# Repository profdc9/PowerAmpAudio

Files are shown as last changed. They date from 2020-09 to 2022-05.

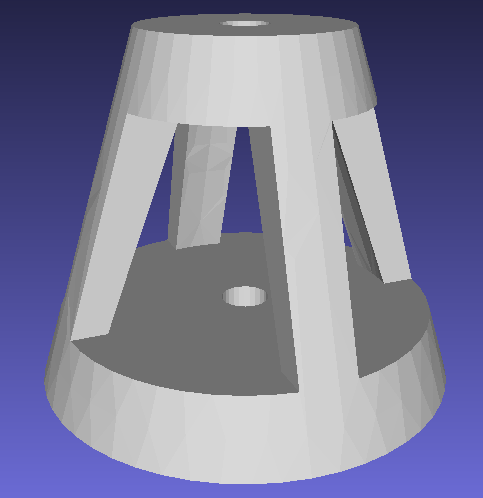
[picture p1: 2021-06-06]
CAD/example-3.5mm.png

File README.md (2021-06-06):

# Modified C300 Amplifier

This is a PCB layout by Daniel Marks based on Michael Chua's C300 amplifier which can be found at:

https://www.ampslab.com/c300.htm

This is a project designed to be a good quality amplifier that is achieves good quality distortion (< 0.1% THD at 10 kHz and 300 W per channel max), and is both educational (to study for electronics engineering and hobbyist use) and archival (to be useful long into the future, or "future proofed").  This is a layout from 2020 but it is assumed that decades into the future, relatively few bipolar transistor models will be available as through-hole and discrete component electronics become ever more rare.  Through-hole and discrete devices are currently being phased out from major manufacturers, however, Chinese and other second-source manufacturers are still producing them.  Therefore emphasis with this design has been placed on keeping the design simple with a minimal number of part types and flexible substitution, perhaps at the expense of the performance that could be achieved at using the very best parts available in 2020.  

There are five PCBs in this project:

1.  PowerampC300 - a C300 power amplifier that uses TO220 transistors (BCE layout) as the intermediate power transistors, with the benchmark devices being MJE15032/MJE15033.
2.  PowerampC300TO126 - the same power amplifier that uses TO126 devices (ECB layout), the benchmark devices being MJE340/350.
3.  A power conditioning board (PowerCond) intended to provide clean power to the PCBs and isolate the power between the channels, as well as enable the use of switching power supplies by filtering switching noise.  It may also be used with a conventional unregulated supply (diode bridge and filter capacitors).
4.  A PCB with XLR to unbalanced conversion.  This is currently using a THAT1200 part but can be reconfigured for other types of chips from Analog Devices SSM2131 or Texas Instruments INA134.  
5.  SoftStart - a relay based soft start which supports external triggering mode from an AV receiver.  This PCB prevents current inrush when an unregulated supply with large reservoir capacitors are used.

The small signal transistors are of 2N5401/2N5551 type (though MPSA42/MPSA92 may be substituted, with the THD approximately doubling because of the reduced loop bandwidth as the beta of these transistors is smaller).  Q1/Q2 may be advantageously substituted with MPSA18 if available to decrease the noise at the input.

The power transistors may be of many TO-247 or TO-264 types as available.  The footprints for the power transistors allow for under PCB, over PCB, or surface lead mounting.

There are only three types of transistors that are needed for this project to keep : a small signal, high voltage type (for example 2N5401/2N5551), a medium power type (for example MJE15032/MJE15033 or MJE340/MJE350), and a high power output stage type (for example MJL3281A/MJL1302A).

The original design calls for mica capacitors for C9 and C6.  C6 generally is not needed and can be left open, but 10 pF maximum should be used for a small amount of phase lead if required.  A good choice for C9 is 100 pF which should provide reasonable stability for a wide variety of transistor types.  As silver mica capacitors are becoming more rare, C0G/NP0 capacitors with 1 kV minimum voltage may be substituted in a pinch.  Most of the other capacitors of 0.1 uF size are either polypropylene film capacitors (7.5 to 10 mm footprint) or ceramic disc type (5 mm footprint).  As polystyrene capacitors are already exceedingly rare in 2020, the best substitute is likely to be polypropylene capacitors.  In particular, X7R/Y5V types use a ferroelectric dielectric and therefore are "microphonic" in that the sound will be converted to a small voltage by these capacitors, in a manner similar to that of an electret microphone, and therefore these should be avoided except in a handful of places where their influence is minimized.

C1 is a 10 uF decoupling polyethylene film capacitor.  It is fairly large.  Should it not be available, something like two 22 uF, 100 to 250V (larger the better) electrolytics can be used, wired in series with negative terminals joined.  Electrolytics, however, have somewhat higher distortion than film capacitors.

Resistors should be of metal-film types, except R33-R40 which may be wirewound.

THe inductor L1 is an output inductor intended to improve stability for highly capacitive loads (e.g. electrostatic speakers).  It may be a coil of 16-18 gauge magnet wire, 10 turns and 25 mm diameter.

All of the gerbers are available as well as the Kicad files, which is an open-source PCB layout program.  The PCBs are two-layer boards.  Modelling of the amplifier (both open-loop and distortion) has been performed with Qucs-S/ngspice with these simulation files included.

# WARNINGS

This project involves high voltages, high currents, and high power.  You must take proper precaution to prevent injury or death from electrocution.  The voltages and currents could cause excessive heating or electrical fires.  You must take proper precautions to properly ground equipment, especially mains voltages, so that these do not come in contact with the chassis possibly cause electrocution.  The chassis of the equipment should be attached to earth ground with proper fusing.  Large amounts of energy may be stored in capacitors.  If this energy is suddently discharged, for example from accidentally shorting the terminals, injury may result, and the capacitor may be damaged or explode.  Wiring electrolytic capacitors in reverse polarity is likely to cause damage or explosion.  This list of potential dangers is not exhaustive; you assume all risk.

# Part substitutions

## Transistors

The small signal transistors are chosen to be 2N5551 (NPN) and 2N5401 (PNP).  These should have Vcemax of at least 150 V, minimum collector current 100 mA, hFE at least 100, and gain-bandwidth product 100 MHz or greater.  MPSA42 (NPN) and MPSA92 (PNP) may be subsituted for 2N5551/2N5401, however, these have reduced gain so that the loop gain is reduced and the distortion is somewhat increased.

Because the lead order of TO-126 transistors (ECB) is the opposite of the lead order for TO-220 transistors, TO-126 made be substituted for TO-220 (and vice versa) as long as the device is placed reversed in the PCB (pin 1 and pin 3, and pin 3 at pin 1).  This can not be done with the driver transistors Q15/Q16 because these are against the heat sink and therefore can not be reversed in place.  Therefore, if one wishes to use TO-220 driver transistors but TO-126 VAS transistors, one should use the PowerampC300 project (and not the PowerampC300TO126 project) so that the driver transistors will be oriented correctly to be placed against the heatsink.

The VAS transistors (Q10 and Q12) should have Vcemax at least 200 V, minimum collector current 100 mA, hFE at least 70 (more the better), and gain-bandwidth product at least 15 MHz.  Suitable devices are:

TO-220:  MJE15032 (NPN), MJE15033 (PNP), 3DA4793 (NPN), 3CA1387 (PNP)

TO-126:  MJE340 (NPN), MJE350 (PNP), 2SC3503 (NPN), 2SA1381 (PNP)

The bias servo transistor doesn't need to be anything special should have Vcemax at least 200 V.  Suitable devices are the same types used for the VAS transistors.  

The driver transistors should have Vcemax at least 200 V, minimum collector current 1 A, hFE at least 50, and gain-bandwidth product at least 15 MHz.  Suitable devices are:

TO-220:  MJE15032 (NPN), MJE15033 (PNP), 3DA4793 (NPN), 3CA1387 (PNP)

TO-126:  MJE340 (NPN), MJE350 (PNP)

The output transistors are TO-247/TO-264/TO-3P type.  They should have Vcemax at least 200 V, minimum collector current 15 A, hFE at least 50, and power dissipation at 25 C at least 150 W.  Suitable types include:

MJL3281A (NPN) / MJL1302A (PNP)  TO-264

MJL3281W (NPN) / MJL1302W (PNP)  TO-247

NJW0281 (NPN) / NJW0302 (PNP) TO-3P

2SC5200 (NPN) / 2SA1943 (PNP) TO-264

MJL21194 (NPN) / MJL21193 (PNP) TO-264

MJW21194 (NPN) / MJW21193 (PNP) TO-247

There are known to be versions of the MJL15032, MJL15032, NJW0281, NJW0302 available from by Chinese vendors (search lcsc.com).  These may have sufficient performance for creating lower cost implementations of the amplifier. 

## Power terminals

The power terminals are designed to take the common 5.0/5.08 mm spaced screw terminal blocks.  Alternatively, 6.35 mm male spade terminals with 5.0 mm pitch pins may be soldered into the board.  Screw terminal blocks are easier to swap out but are not as secure, while spade terminals can be quite secure but sometimes difficult to remove if required.

## Audio connectors

To connect unbalanced audio to the amplifier PCBs and to the balanced to unbalanced PCBs, either two wires or a SMA cable may be used.  A SMA cable has the advantage of inherent shielding.  If a SMA cable is wired to an input unbalanced RCA jack, the jack should be an isolated jack with the ring of the jack wired to the input star ground where the chassis earth ground is.

## Balanced to unbalanced differential line receiver

The balanced to unbalanced PCB can be set up to preferentially use the THAT1200, but also can be configured for the THAT1240, INA134, or SSM2141.

# Building the amplifier (PowerampC300 and PowerampC300TO126)

The PCB is two-sided without any links with all components soldered to the top side.  Populate the small components first (transistors, resistors, small capacitors).  Leave the larger components such as C1, Q10, Q11, Q12, Q15, Q16, the driver transistors Q17-Q24 for later as they will make the PCB more unwieldy to work with.

Q10 and Q12 should be mounted to small vertical heatsinks sufficient of dissipating 10 W.  An insulating silicone pad or mica sheet should be placed between the collector tab and the heatsink so that the heatsink is not electrically connected to the transistor.  A bushing should be used on TO-220 types of insulate the mounting screw from the heatsink.

Q15, Q16, and Q17-Q24 are all mounted in a row to a heatsink.  There is a file "Drillpattern.pdf" which shows the position of the holes on the heatsink for the transistors which can be taped over the heatsink to mark the positions to tap.  All of these transistors should have silicone pads or mica sheets insulating the collector tabs from the heatsink.  AFTER INSTALLATION, THE HEATSINK SHOULD BE CAREFULLY CHECKED WITH A MULTIMETER TO MAKE SURE THERE IS NO CONTINUITY BETWEEN THE COLLECTORS (middle pin) OF ANY OF THE TRANSISTORS AND THE HEATSINK.  For an aluminum heatsink, M3 (metric) or 4-40 (SAE) holes may be tapped in the heatsink to mount the transistors.  After tapping, there is likely to be burrs from the tapping process, so sanding the heatsink with the a fine sandpaper is often require to remove these burrs.  These burrs may poke through a silicone pad or mica sheet and contact the transistor causing a potentially catastrophic short circuit.  If Q15 and Q16 are TO-220 transistors, a bushing should also be used to insulate the tab from the mounting screw.  It is helpful when installing the transistors to gently curl the legs away from the heatsink slightly so that they can be easily bent if a little persuasion is needed to make the position of the transistor mounting hole reach the tapped hole.  

A hole should be tapped on the heatsink above Q15 and Q16 to place the bias servo transistor Q11.  The three legs of Q11 are soldered to extension wires, and heat shrink tubing is applied to the extension wires to prevent inadvertent contact the between the wires or to the heatsink.  The other end of the wires are soldered into the PCB at the Q11 position so that Q11 is tethered to the PCB but may freely moved.  Q11 can be mounted to the heatsink similarly to how Q15 and Q16 are, using an insulating silicone or mica pad and a bushing if required.  Again, check to make sure there is no continuity between the heatsink and the collector of Q11.

The heatsink may be mounted with the transistors laying flat parallel to the PCB, or the heatsink stood upright so the transistors are sticking up from the PCB.  Which one is used depends on the case mounting and heatsink type.

After assembly carefully inspect the PCB front and back, especially solder pads for any accidental bridges or incomplete or cold solder joints.  A lighted magnifier is very helpful for this.  If joints are not being properly made, it could be because the solder is old and has bad flux or the board was not clean before starting.  This is particularly troublesome to make reliable solder joints, and fresh flux should be applied to ensure joints are properly wetted.

CONNECT THE POSITIVE SUPPLY LEADS (GND/V+) to the PCB before the negative supply leads (V-/GND).  If there is only a negative supply attached to the amplifier PCB, the amplifier may be damaged (transistors Q8 or Q9).  Before powering, the DC offset control trimmer R10 should be set to the middle position in resistance (approximately 50 ohms between wiper and contacts), and bias control trimmer R22 should be to maximum resistance (200 ohms).  

The file "Grounding.pdf" shows a diagram of how to connect the amplifier to minimize ground loops.  Pay attention to isolate the jacks from the chassis, twist the conductors of the power together, twist the conductors of the output cables together, and bond the input jacks together and possibly to one point on the chassis.

Powering up for the first time is always a nerve-racking experience.  All power connections from the transformer to the power conditioning PCB to the amplifier PCB should be thoroughly checked to ensure that both supplies are properly connected.  The best approach is to use an isolated variac with a AC current meter to power the amplifier so that the voltage may be slowly increased and it can be seen if any excessive currents are encountered.  However, if a variac is not available, one may be able to place 220 ohm, 5 watt resistors in series with the positive and negative rails so that when one initially powers on, the full current available from the power supply does not cause excessive damage to the PCB if there is a problem.  

The amplifier should first be powered up without a load.  If there is a faulty component or faulty connections, such as unreliable power connections, the amplifier may oscillate.  This sometimes often results in the destruction of Q8, and occasionally R19 and R24.  Damage to the resistors is usually obvious and can easily be tested in circuit.  Q8 can still measure properly with a diode checker in circuit but be faulty.  Therefore one should replace Q8 if there is any doubt if it is functioning correctly.

Once the amplifier has operated at full voltage without a load, a dummy load should be attached to the amplifier output.  A dummy load can be constructed, for example, from many smaller 8-ohm, 5 W sandblock or metal-oxide resistors.  For example, thirty six of these resistors, with 6 strings of resistors in parallel, each string being 6 resistors in series, makes a convenient 180 watt, 8 ohm audio load.  

The quiescent current of the class AB stage should be set.  Trimmer R22 controls the voltage bias between the bases of the NPN and PNP transistors and therefore the quiescent current.  By decreasing the resistance of R22, the quiescent current is increased.  The quiescent current of an output transistor may be measured using the voltage between the emitter of the transistor and the output of the amplifier.  With R22 at maximum resistance, this should be very close to 0 mV.  Slowly decrease the resistance of R22, measuring the increase of the voltage.  Because the voltage is across the output 0.39 ohm resistor, to achieve 35 mA quiescent current, 14 mV should be measured.  Because of differences between transistors, the quiescent currents in different transistors are likely to be slightly different.  Try to ensure that no output transistor has excessive current, perhaps exceeding 60 mA.  

Without any input to the amplifier, when the amplifier is powered up, the DC voltage measured across the 8 ohm audio load should read very close to zero, within 100 mV at most.  Trimmer R10 should be adjusted to reduce the DC offset at the output to below 10 mV.  

With the quiescent current and output DC offset adjusted, you can apply a signal to the amp.  Use an oscilloscope to measure the voltage on the audio load.  Inject a sine wave input signal into the amplifier of about 1000 Hz and 0.1 V peak.  Because the gain of the amplifier is approximately 31, this should result in a 3.1 V output on the audio load.  The signal can be generated either by a signal generator, or by a computer sound card which is input into a preamplifier.  Turn the preamplifier down and adjust the input signal amplitude.  A very clean sine wave output should be observed.

Slowly increase the amplitude of the sine wave, up to perhaps 1.0 V, so that the peak output voltage is 31 V.  A clean sine wave should still be observed.  The audio load will start to get hot, so keep the audio load on a surface (for example a ceramic dish) to insulate it from the table.  

Next, change the output from a sine wave to a square wave at 20 kHz.  A nice, clean square wave should be observed with little or no ringing.  The rise/fall time on the square wave should be about 2 microseconds or so.

Once you are confident that the amplifier is stable, you can try your (not best) speaker with it.  A pure tone should be heard without distortion.  If you are hearing hum, you may have a problem with grounding inside the amplifier or a ground loop.  If you short the input to the amplifier, and still hear hum, the problem is inside the amplifier.  Check to see that the amplifier is grounded at the input jacks (and only there) to the earth ground connection on the chassis.  If not in the amplifier, you may need to investigate if the device generating the signal has multiple ground connections inside it.

After all of this, you should be good to go.  Be careful as the amplifier has a lot of power and can damage speakers not rated for the full power.

# Building the power conditioning board

The power conditioning board is not strictly required.  However, it serves three functions.  It rectifies AC to DC when an unregulated transformer supply is used.  It serves to filter out RF noise and brief voltage spikes from the diode commutation from the amplifier, as well as any other noise coming from the mains.  The filtering is also useful is one uses switching power supplies rather than an unregulated transformer supply to filter the switching noise.  Finally, it serves as a terminal block to connect the reservoir capacitors and amplifier.  Typically, one power conditioning board is used per channel.

The common mode chokes can be constructed by hand.  Four are required for each power conditioning board.   Typically, small ferrite toroids are obtained, usually between 16 to 25 mm in outer diameter.   Small green cores available widely on sites like ebay, Amazon, or aliexpress are suitable.  The primary and secondary turns are two different colors of 18 AWG (1 mm diameter) solid copper wire.  The two wires are wound together side-by-side through the core five or six times.  When soldering the core into the PCB, the silkscreening shows how the wires are connected.  The same color wire is soldered to both pads connected by the line in the silkscreen.  The same ends of the two wires are soldered to the two pads next to each other on the same side of the PCB.  Solder should be applied to both the top side and bottom side of the pad to ensure the wire is held solidly.

The mounting holes at the corners of the PCB are intended to be grounded to the case through standoffs to shunt the filtered RF noise signal to the case.  

# Building the SoftStart board

The SoftStart board is relatively straightforward to build.  Special attention should be paid to acquiring X2 capacitors for C1 and C2.  The extra non-plated through holes in the PCB are so that the mains and switch wires soldered to the PCB can be threaded through the PCB and collared with a cable tie as a strain relief so that it does not pull out of the PCB.  The cable tie will prevent stress from being applied to the solder joint on the PCB.  Generally, a cover should be placed over the back side of the PCB (for example a polycarbonate sheet) to prevent contact of the solder joints with the case.  It is highly recommend to put heat shrink tubing over any exposed mains connections, for example, at the power entry panel, switch or fuse holder.  

Depending on the size of the reservoir capacitors in your amplifier, it may be necessary to change the 150 ohm resistors to a smaller value and allow a somewhat larger charging current before the resistors are bypassed by the relay.  This depends on the peak current that is permitted.

# Building the XLR to Unbalanced board

This board uses the THAT1200 balanced line receiver to transform the signal from a balanced XLR connector to an unbalanced signal.  The unbalanced signal may be connected from the XLR to Unbalanced board to the amplifier board with a shielded SMA cable to prevent noise pickup.  If the THAT1200 is not available, the THAT1240, INA134, or SSM2141 balanced line receivers may be used.  In this case, C5 and C17 should be omitted and JP1 and JP2 are shorted.

The transistors Q1 and Q2 should have heatsinks attached and fitted with pads and bushings to electrically isolate the heatsink from the collector.  J12 is a ground terminal block from which a grounding wire and lug may be extended to the common input grounding point on the chassis of the amplifier.

# Different types of feedback

There are three kinds of feedback that can be customized to provide a tradeoff of distortion vs. loop stability.  Some audiophiles like to attain the minimum distortion.  It is likely that the distortion is sufficiently low, especially at power levels significantly below the maximum power, that distortion is not likely to be noticed.  It is highly recommended when using compensation methods that could be more unstable that the inductor L1 is installed, as any significant capacitive loading is likely to cause oscillation.

For the audiophile true believers, three feedback options are provided: Conventional Miller Compensation (CMC), Two-Pole Compensation (TPC), and Output Inclusive Two-Pole Compensation (OITPC).  Small value capacitors are ideally silver mica type (470 pF or less), but NP0/C0G types can work as well.  The 100 nF are polypropylene film capacitors, 100 V or more.

## Conventional Miller Compensation (CMC)
As shown, the circuit is configured for CMC.  In this case, C9=150 pF, C3=150 pF, C25 is a shorting wire, R18, C20, and C24 are not included.  For slightly less distortion, C9=100 pF and C3=100 pF. 

## Two-Pole Compensation (TPC)
To configure for Two-Pole Compensation, C3 and C20 are not included, C9 and C25 are 220 pF, R18 is 2k2, and C24 is 100 nF.  Simulations suggest that at mid range frequencies, distortion can be decreased by 14 dB, and at 10 kHz by 8 dB.

## Output Inclusive Two-Pole Compensation (OITPC)
OITPC is a relatively new option that is included for study and experimentation.  To configure for OITPC, C9 and C25 are 100 pF, R18 is 390 ohms, C20 is 100 pF, and C24 is 100 nF, C3 is not included.  

# A brief explanation of the operation of the amplifier
The amplifier is a class AB configuration with approximately 34 dB of gain and employing global negative feedback, as well as local feedback in the form of compensation.

Capacitor C1 is a film capacitor that isolates DC from the input but passes frequencies above 2-3 Hz.  Q1 and Q2 are a differential pair for which the error feedback signal is the current through the collector of Q1.  

R6, R7, R8, R9, and R10 are used to null any DC offset on the output, with the potentiometer R10 fine-tuning the DC offset.  Q7 is a constant current source with a fixed voltage between its base and emitter which is determined by the red LED.  The emitter resistor R12 sets the current at approximately (LED voltage=2.0 V - 0.7 VBE) / R12.  The same LED also sets the voltage on the emitter of Q12 which is likewise a constant current source for the VAS (voltage amplification stage).

Q5 and Q6 have their bases joined together and fixed at a voltage 33 V above ground so that their emitters are fixed at one diode drop below the bases.  This is a cascode configuration that holds the collectors of Q1/Q2 at a constant voltage as to reduce the Miller effect.  This is also helpful to limit the VCE of Q1 and Q2 in case a low voltage transistor such as MPSA18 is used, which has a maximum VCE of 45 V.

Q3 and Q4 are a current mirror forming a high impedance load for the differential pair so that high gain is achieved.  The output impedance of Q3 is limited by the Early effect which can be at quite a high voltage for a high voltage transistor such as 2N5401.  R5 and C3 form a high-pass network which serves to help increase the phase margin at high frequencies by reducing the open loop gain at high frequencies.

Because Q3 acts as a high impedance load, the current from Q1 is steered into the base of Q8 which is an emitter-follower configuration.  This minimizes the load of Q1.  Q8 is a vulnerable transistor as it drives Q10 with whatever current is necessary to maintain feedback, even when the amplifier is at the rails.  To prevent the current in the collector of Q8 from exceeding safe operating limits, transistor Q9 steals base current from Q8 when the current in the VAS exceeds about 20 mA.  This is one diode drop across the emitter-base of Q9 divided by resistor R19.  If Q9 is not present a brief excursion into the rails can destroy Q8 as the voltage and current on it can greatly exceed tolerable limits.

Q10 and Q12 are a conventional one-sided VAS arrangement, with Q12 being a constant current source of about 11 mA, and Q10 being a common-emitter configuration.  This produces a second high gain stage, which when combined with the gain of the differential pair, produces the needed open loop gain in the amplifier.

With C9 at 100-150 pF and C25 short circuited, this amplifier employs conventional Miller compensation.  This is a negative feedback arrangement that introduces a pole into the open loop gain of the amplifier.  It is the main mechanism stabilizing the amplifier.  The pole ensures that any other poles in the amplifier due to limited component bandwidth occur with a gain margin of 10 dB or greater.  By including a capacitor at C20, the compensation includes the output signal and partially compensates for the relatively slow speed of the output transistors.

Transistor Q11 is in a "rubber diode" configuration that is an adjustable fixed bias to achieve a quiescent current in the output transistors Q17 to Q24.  The voltage differences between the bases Q17, Q19, Q21, and Q23 and Q18, Q20, Q22, and Q24 determine the quiescent current.  More quiescent current generally reduces crossover distortion but dissipates more constant power.  Potentiometer R22 is used to adjust the quiescent current, which is typically about 10 to 15 mA per output transistor, and is typically measured across the resistors R33-R40. 

D13 and D14 are catch diodes that limit the output current at very high current output.  When the diodes are forward biased, VAS current is diverted directly to the output, limiting the base current of Q13 and Q14 and therefore output current of the amplifier.

Q13 and Q14 are a V-I limiter which limits the output current when the impedance of the load drops below 2 ohms.  The voltage is sensed on the emitter resistors R39 and R40.  This is reduced by the divider networks R26/R29 and R27/R30.  When the emitter-base voltage on Q13 or Q14 exceeds one diode drop, or about 0.6 V, the transistors start to steal base current from Q15/Q16 which limits the output current.  This acts as a temporary protection for the output transistors to keep them within the safe operating area.  However, it is recommended to use a fuse on the power supply as well so that in case of a prolonged short circuit, the fuse blows.

Q15/Q16 and the output transistors Q17-Q24 form a conventional Darlington class AB stage.  As the VAS can source a maximum of about 10 mA, the hFE of Q15/Q16 is about 50, and the hFE of Q17-Q24 is about 50, the maximum current is on the order of 15 to 25 A, which corresponds to a very high peak power.  However, four transistors are needed as the thermal load is shared between them, and dividing the current load between them ensures they are kept within the SOA.  It is recommended that if 2SC5200/2SA1943 transistors are used, the maximum supply voltage is limited to 50 to 55 V as the SOA of these transistors is somewhat less than the MJL3281A/MJL1302A which can handle up to 70 V.

R52 and U1 are yet another optional feature to protect the amplifier.  When the output current exceeds 8 A, the optotriac U1 LED turns on which triggers the triac.  This short circuits the bias at the output so that the catch diodes D13 and D14 divert the VAS current into the output and the output is mostly turned off.  The output remains off until the power is cycled.  This feature may be needed for those that torture and damage the amplifier regularly, but is probably not needed for ordinary use.

This amplifier can be used with vertical MOSFETs by substituing Q17, Q19, Q21, and Q23 with IRFP240 and Q18, Q20, Q22, and Q24 with IRFP9240.  However, R21 needs to be substituted with a much larger resistance so that the gate-to-gate voltage is much larger, on the order of 1.5k ohms.  Secondly, a diode connected transistor (base and collector shorted) needs to be placed in series with the emitter of Q11, and this diode connected transistor should be connected to the heatsink.  The necessary quiescent current for MOSFETs in order to achieve low crossover distortion is much greater than that of BJTs, on the order of 200 mA for all the transistors. The voltage between the gates will be on the order of 2 VT or about 8 V.  This however has not been extensively tested at the time of writing.

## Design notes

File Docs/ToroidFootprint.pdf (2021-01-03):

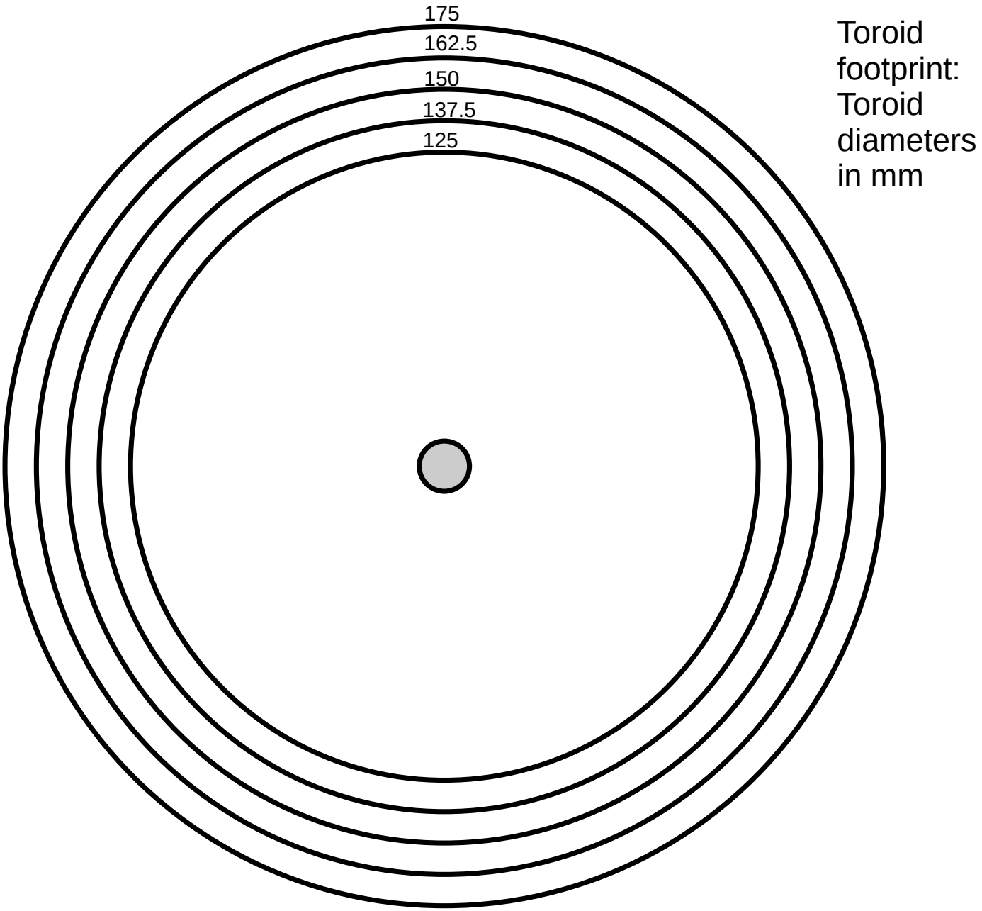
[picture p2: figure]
Toroid footprint: Toroid diameters in mm

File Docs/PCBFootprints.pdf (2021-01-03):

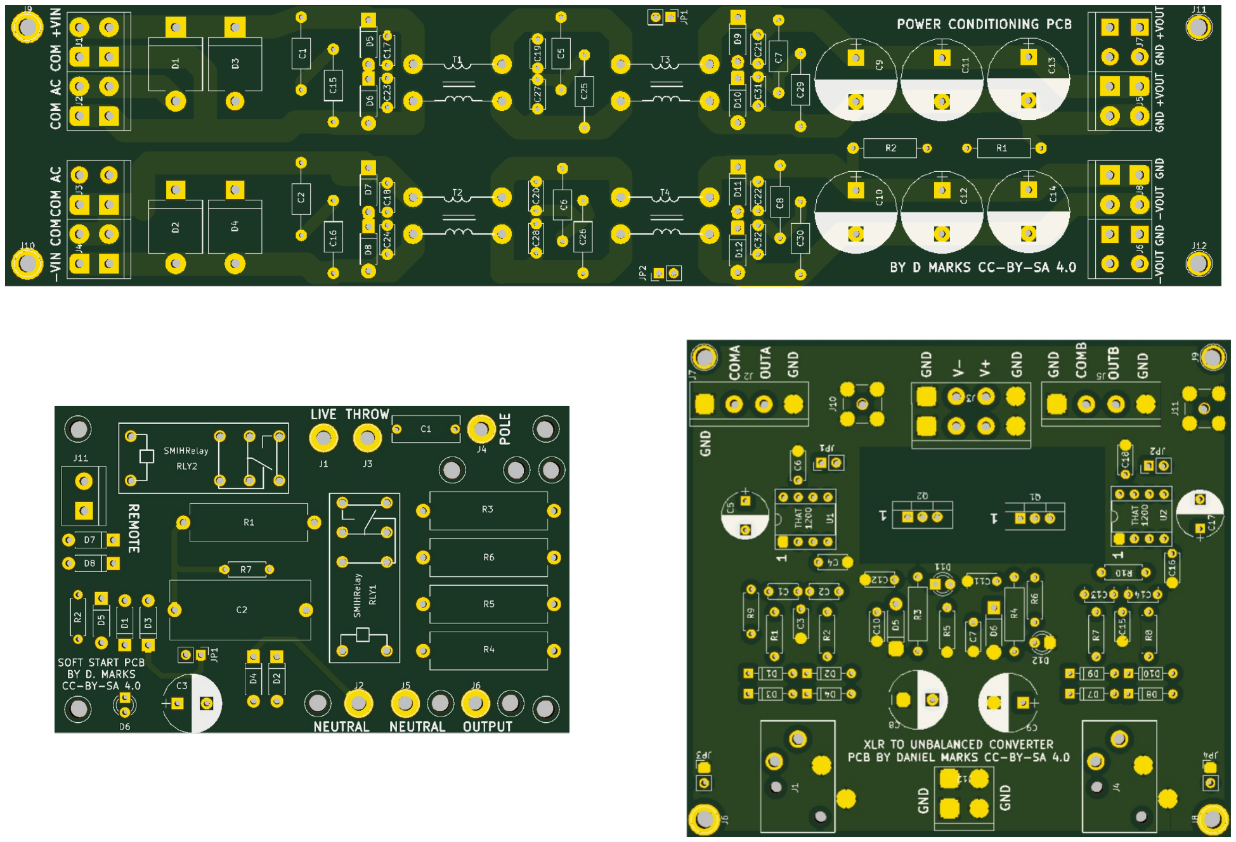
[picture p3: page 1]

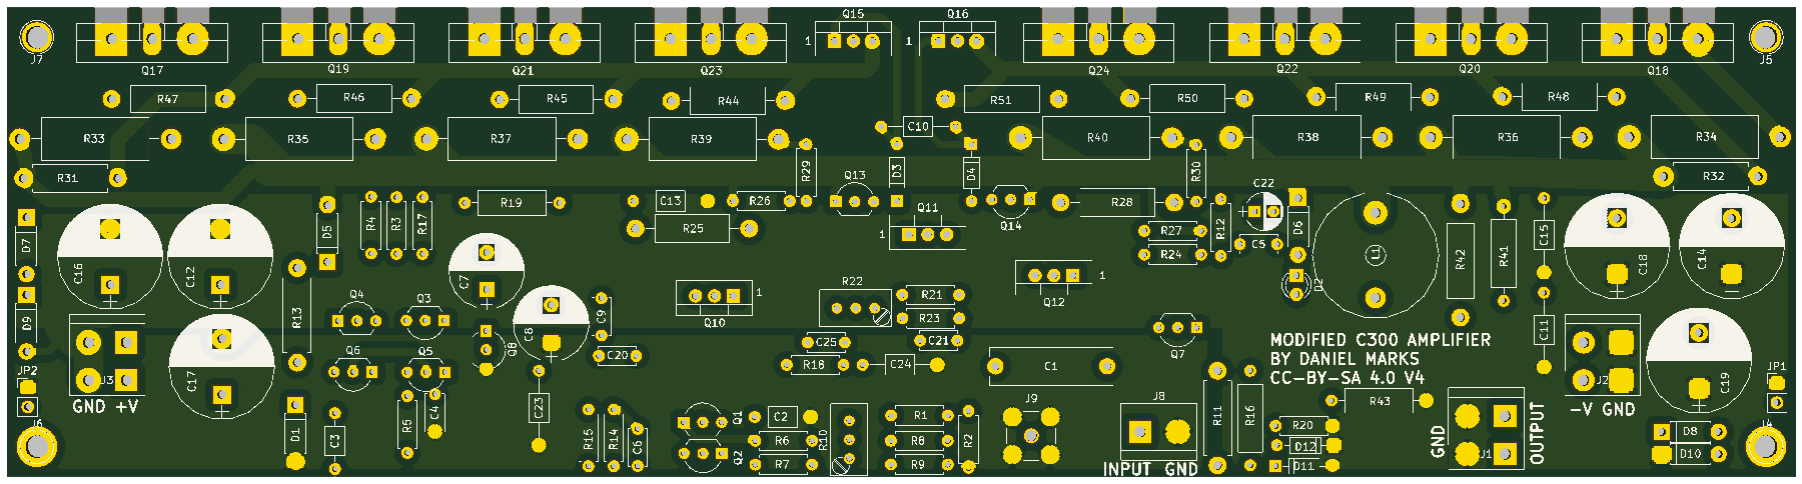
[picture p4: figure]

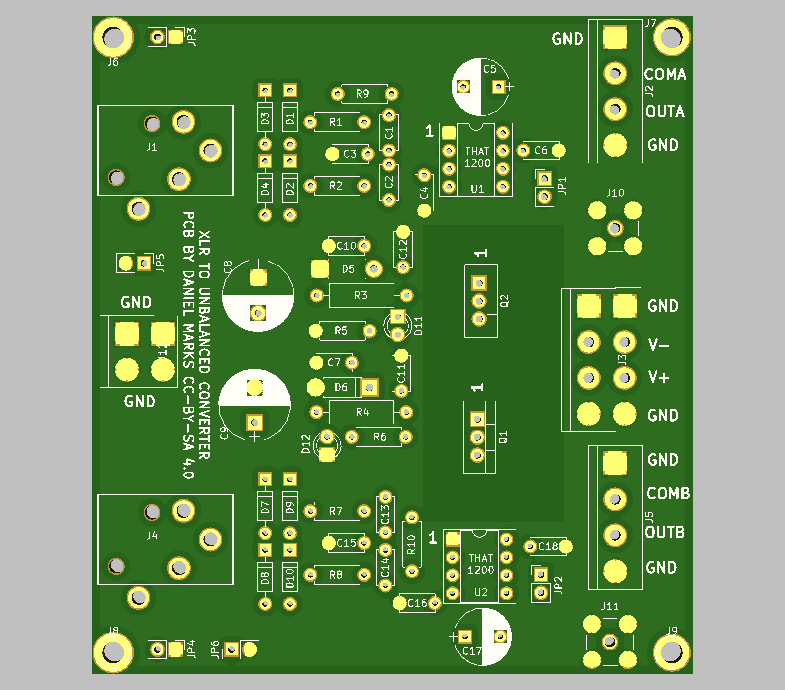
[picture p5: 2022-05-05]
XLRtoBal/XLRtoBal.png

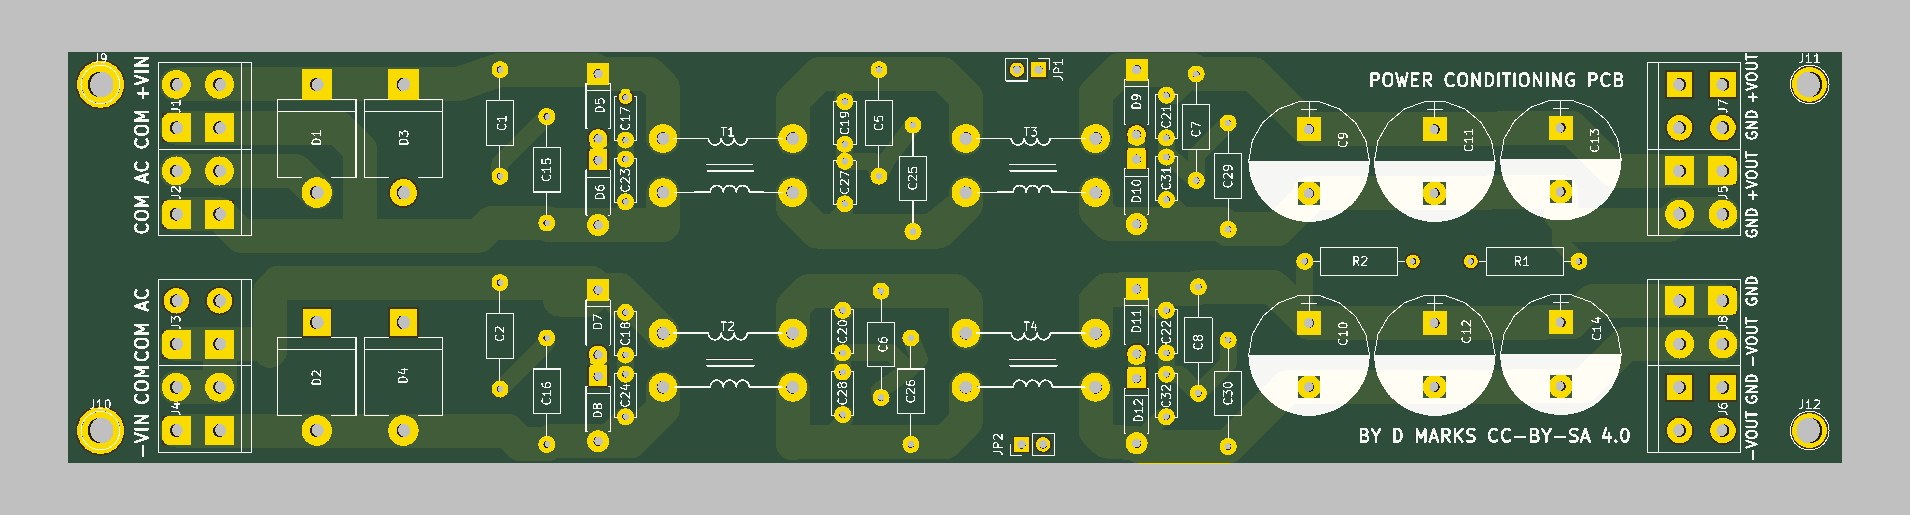
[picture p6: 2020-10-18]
PowerCond/PowerCond.png

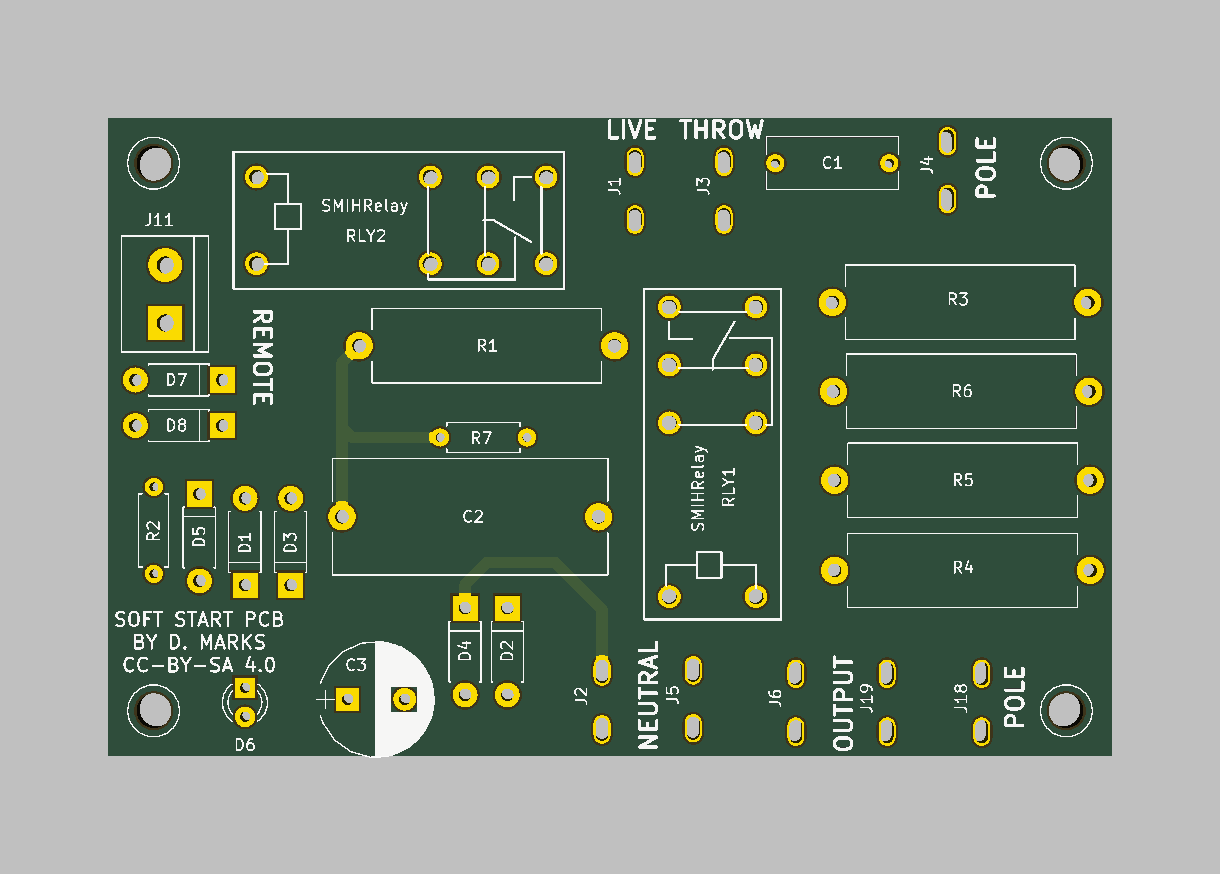
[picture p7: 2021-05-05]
SoftStart/SoftStart.png

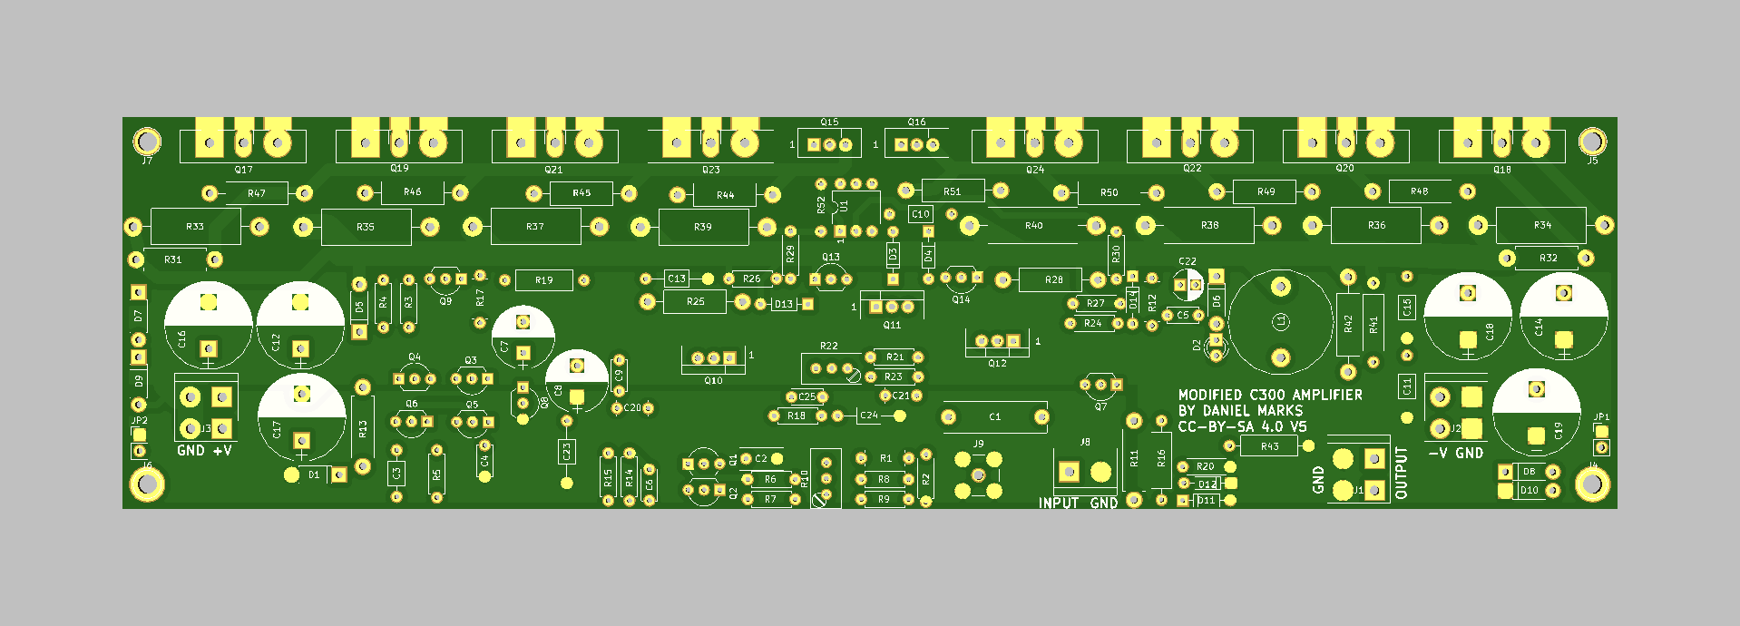
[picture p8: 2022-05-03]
PowerampC300/PowerampC300.png

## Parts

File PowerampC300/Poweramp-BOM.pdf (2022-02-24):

PowerampC300

Designator | Footprint
C1 | 10 uF polypropylene film capacitor > 63 V
C10,C11,C13,C15,C23,C24 | 0.1 uF / 100 nF polypropylene film capacitor > 250V
C12,C14,C16,C17,C18,C19 | 100 uF electrolytic capacitors > 160 V
C2 | 470 pF polypropylene film capacitor
C21 | NC (could place 10 uF ceramic here)
C22 | NC (could place 47 uF > 50V electrolytic here)
C25 | 0 ohm resistor (¼ watt) or wire
C3 | 100 or 150 pF mica or ceramic C0G capacitor
C4,C5 | 0.1 uF / 100 nF ceramic disc capacitor
C6,C20 | NC
C7,C8 | 1000 uF, 10 V electrolytic capacitor
C9 | 100 or 150 pF mica or ceramic C0G capacitor
D1 | 33 V zener diode
D2 | 3 mm RED LED
D3,D4,D11,D12,D13,D14 | 1N4148 DO-35 diode
D5,D6 | 1N4007 DO-41 diode
D7,D8,D9,D10 | 44 V zener diodes
J1,J2,J3 | Male spade quick connectors (or terminal blocks)
J4,J5,J6,J7 | NC
J8 | 2 position 5 mm terminal block
J9 | SMA connector
JP1,JP2 | 2 pin 2.54 mm spacing male pin header
L1 | air core 1 uH (approximate) inductor, 18 gauge/1 mm wire
Q11,Q12,Q15 | TO-220 MJE15032
Q10,Q16 | TO-220 MJE15033
Q17,Q19,Q21,Q23 | TO-264 MJL3281A
Q18,Q20,Q22,Q24 | TO-264 MJL1302A
Q3,Q4,Q8,Q9,Q14 | TO-92 2N5401
Q1,Q2,Q5,Q6,Q7,Q13 | TO-92 2N5551
R1,R5,R17 | ¼ watt 1000 ohms
R10 | 100 ohm potentiometer
R11 | 3 watt 6.8k ohms
R12 | ¼ watt 200 ohms
R13 | 3 watt 5.6k ohms (could use 6.8k ohms here)
R15 | ¼ watt 330 ohms
R16 | 1 watt 6.8k ohms
R18 | NC
R19 | 3 watt 33 ohms
R2,R14 | ¼ watt 10k ohms
R20 | ¼ watt 10 ohms
R21 | ¼ watt 390 ohms
R22 | 200 ohm potentiometer
R24,R29,R30 | ¼ watt 120 ohms
R25,R28 | 3 watt 6.8k ohms
R26,R27 | ¼ watt 33 ohms
R3,R4 | ¼ watt 180 ohms
R31,R32 | 3 watt 33 ohms
R33,R34,R35,R36,R37,R38,R39,R40 | 5 watt 0.39 ohms, noninductive sandblock resistor

PowerampC300

R41 | 3 watt 4.7 ohms
R42 | 3 watt 4.7 ohms
R43 | 3 watt 10k ohms
R44,R45,R46,R47,R48,R49,R50,R51 | 1 watt 1 ohm
R6,R7,R23,R52 | ¼ watt 100 ohms
R8,R9 | ¼ watt 56 ohms
U1 | NC

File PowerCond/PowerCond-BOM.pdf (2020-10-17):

PowerCond

Page 1

Source: | E:/Poweramp/PowerCond/PowerCond.sch
Date: | 10/16/2020 9:42:15 PM
Tool: | Eeschema 4.0.7
Component Count: | 62
Ref | Value
C1 | 1 uF, 250 V polypropylene
C2 | 1 uF, 250 V polypropylene
C5 | 1 uF, 250 V polypropylene
C6 | 1 uF, 250 V polypropylene
C7 | 1 uF, 250 V polypropylene
C8 | 1 uF, 250 V polypropylene
C9 | 100 uF, 160 V electrolytic
C10 | 100 uF, 160 V electrolytic
C11 | 100 uF, 160 V electrolytic
C12 | 100 uF, 160 V electrolytic
C13 | 100 uF, 160 V electrolytic
C14 | 100 uF, 160 V electrolytic
C15 | 1 uF, 250 V polypropylene
C16 | 1 uF, 250 V polypropylene
C17 | 1 nF, 1 kV ceramic disc capacitor
C18 | 1 nF, 1 kV ceramic disc capacitor
C19 | 1 nF, 1 kV ceramic disc capacitor
C20 | 1 nF, 1 kV ceramic disc capacitor
C21 | 1 nF, 1 kV ceramic disc capacitor
C22 | 1 nF, 1 kV ceramic disc capacitor
C23 | 1 nF, 1 kV ceramic disc capacitor
C24 | 1 nF, 1 kV ceramic disc capacitor
C25 | 1 uF, 250 V polypropylene
C26 | 1 uF, 250 V polypropylene
C27 | 1 nF, 1 kV ceramic disc capacitor
C28 | 1 nF, 1 kV ceramic disc capacitor
C29 | 1 uF, 250 V polypropylene
C30 | 1 uF, 250 V polypropylene
C31 | 1 nF, 1 kV ceramic disc capacitor
C32 | 1 nF, 1 kV ceramic disc capacitor
D1 | 10A10
D2 | 10A10
D3 | 10A10
D4 | 10A10
D5 | 1N4755A, 44 V zener diode
D6 | 1N4755A, 44 V zener diode
D7 | 1N4755A, 44 V zener diode
D8 | 1N4755A, 44 V zener diode
D9 | 1N4755A, 44 V zener diode
D10 | 1N4755A, 44 V zener diode
D11 | 1N4755A, 44 V zener diode
D12 | 1N4755A, 44 V zener diode
J1 | 2 position terminal block
J2 | 2 position terminal block

PowerCond

Page 2

J3 | 2 position terminal block
J4 | 2 position terminal block
J5 | 2 position terminal block
J6 | 2 position terminal block
J7 | 2 position terminal block
J8 | 2 position terminal block
JP1 | 2 position pin header 2.54 mm spacing
JP2 | 2 position pin header 2.54 mm spacing
R1 | 220k ½ watt
R2 | 220k ½ watt
T1 | Common-mode choke
T2 | Common-mode choke
T3 | Common-mode choke
T4 | Common-mode choke

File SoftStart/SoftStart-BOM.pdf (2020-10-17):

SoftStart

Page 1

Source: | E:/Poweramp/SoftStart/SoftStart.sch
Date: | 10/16/2020 9:46:26 PM
Tool: | Eeschema 4.0.7
Component Count: | 37
Ref | Value
C1 | 10 nF X2 capacitor
C2 | 1 uF X2 capacitor
C3 | 1000 uF, 50 V electrolytic capacitor
D1 | 1N4007
D2 | 1N4007
D3 | 1N4007
D4 | 1N4007
D5 | 1N4749, 24 V zener diode
D6 | LED
D7 | 1N4742, 12 V zener diode
D8 | 1N4742, 12 V zener diode
J11 | 2 pin terminal block
R1 | 220R, 5 W sandblock resistor
R2 | 2k2, ¼ watt resistor
R3 | 150R, 5 W sandblock resistor
R4 | 150R, 5 W sandblock resistor
R5 | 150R, 5 W sandblock resistor
R6 | 150R, 5 W sandblock resistor
R7 | 1M, ¼ watt resistor
RLY1 | Omron G2RL-1-DC24 or equivalent, 24 volt coil, 12 A capacity
RLY2 | Omron G2RL-1-DC12 or equivalent, 12 volt coil, 12 A capacity

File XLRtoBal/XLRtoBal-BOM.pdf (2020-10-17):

XLRtoBal

Page 1

Source: | E:/Poweramp/XLRtoBal/XLRtoBal.sch
Date: | 10/16/2020 9:52:46 PM
Tool: | Eeschema 4.0.7
Component Count: | 60
Ref | Value
C1 | 470 pF NP0/C0G ceramic disc
C2 | 470 pF NP0/C0G ceramic disc
C3 | 100 pF NP0/C0G ceramic disc
C4 | 100 nF ceramic disc
C5 | 220 uF, 10 V electrolytic capacitor
C6 | 100 nF ceramic disc
C7 | 100 nF ceramic disc
C8 | 100 uF, 25 V electrolytic capacitor
C9 | 100 uF, 25 V electrolytic capacitor
C10 | 100 nF ceramic disc
C11 | 100 nF ceramic disc
C12 | 100 nF ceramic disc
C13 | 470 pF NP0/C0G ceramic disc
C14 | 470 pF NP0/C0G ceramic disc
C15 | 100 pF NP0/C0G ceramic disc
C16 | 100 nF ceramic disc
C17 | 220 uF, 10 V electrolytic capacitor
C18 | 100 nF ceramic disc
D1 | 1N4148
D2 | 1N4148
D3 | 1N4148
D4 | 1N4148
D5 | 1N4742, 12 V zener diode
D6 | 1N4742, 12 V zener diode
D7 | 1N4148
D8 | 1N4148
D9 | 1N4148
D10 | 1N4148
D11 | LED
D12 | LED
J1 | IO Technologies IO-XLR3-F-EH
J2 | 4 position terminal block, or two joined two position blocks
J3 | 4 position terminal block, or two joined two position blocks
J4 | IO Technologies IO-XLR3-F-EH
J5 | 4 position terminal block, or two joined two position blocks
J10 | SMA straight PCB connector
J11 | SMA straight PCB connector
J12 | 2 position terminal block
JP1 | 2 position pin header, 2.54 mm spacing
JP2 | 2 position pin header, 2.54 mm spacing
JP3 | 2 position pin header, 2.54 mm spacing
JP4 | 2 position pin header, 2.54 mm spacing
Q1 | TIP41C
Q2 | TIP42C

XLRtoBal

Page 2

R1 | 100R ¼ watt
R2 | 100R ¼ watt
R3 | 6k8, 2 watt
R4 | 6k8, 2 watt
R5 | 2k2, ¼ watt
R6 | 2k2, ¼ watt
R7 | 100R, ¼ watt
R8 | 100R, ¼ watt
R9 | 4k7, ¼ watt
R10 | 4k7, ¼ watt
U1 | THAT1200
U2 | THAT1200
| Note, if THAT1200 is not available, INA134 or SSM2141 can be used.
| In this case, omit C5 and C17 and short jumpers JP1 and JP2.

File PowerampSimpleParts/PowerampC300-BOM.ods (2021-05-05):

 |  | Note configuration as given is for conventional Miller compensation
Ref | Value | Footprint | Datasheet | Manufacturer | Vendor
C1 | 10 uF | Capacitors_THT:C_Rect_L16.5mm_W5.0mm_P15.00mm_MKT | 10 uF film capacitor, 100 V min
C2 | 470 pF | Capacitors_THT:C_Axial_L3.8mm_D2.6mm_P7.50mm_Horizontal | 470 pF film or mica/C0G
C3 | 150 pF | Capacitors_THT:C_Axial_L3.8mm_D2.6mm_P7.50mm_Horizontal | 150 pF mica/C0G
C4 | 0.1 uF | Capacitors_THT:C_Disc_D5.0mm_W2.5mm_P5.00mm | 100 nF, 100 V ceramic disc
C5 | 0.1 uF | Capacitors_THT:C_Disc_D5.0mm_W2.5mm_P5.00mm | 100 nF, 100 V ceramic disc
C6 | NC | Capacitors_THT:C_Disc_D5.0mm_W2.5mm_P5.00mm
C7 | 1000 uF | Capacitors_THT:CP_Radial_D10.0mm_P5.00mm | 10 V electrolytic
C8 | 1000 uF | Capacitors_THT:CP_Radial_D10.0mm_P5.00mm | 10 V electrolytic
C9 | 150 pF | Capacitors_THT:C_Disc_D5.0mm_W2.5mm_P5.00mm | 150 pF mica/C0G
C10 | 0.1 uF | Capacitors_THT:C_Axial_L3.8mm_D2.6mm_P10.00mm_Horizontal | 100 nF, 250+V film
C11 | 0.1 uF | Capacitors_THT:C_Axial_L3.8mm_D2.6mm_P10.00mm_Horizontal | 100 nF, 250+V film
C12 | 100 uF | Capacitors_THT:CP_Radial_D14.0mm_P7.50mm | 100 uF, 160+V electrolytic
C13 | 0.1 uF | Capacitors_THT:C_Axial_L3.8mm_D2.6mm_P10.00mm_Horizontal | 100 nF, 250+V film
C14 | 100 uF | Capacitors_THT:CP_Radial_D14.0mm_P7.50mm | 100 uF, 160+V electrolytic
C15 | 0.1 uF | Capacitors_THT:C_Axial_L3.8mm_D2.6mm_P10.00mm_Horizontal | 100 nF, 250+V film
C16 | 100 uF | Capacitors_THT:CP_Radial_D14.0mm_P7.50mm | 100 uF, 160+V electrolytic
C17 | 100 uF | Capacitors_THT:CP_Radial_D14.0mm_P7.50mm | 100 uF, 160+V electrolytic
C18 | 100 uF | Capacitors_THT:CP_Radial_D14.0mm_P7.50mm | 100 uF, 160+V electrolytic
C19 | 100 uF | Capacitors_THT:CP_Radial_D14.0mm_P7.50mm | 100 uF, 160+V electrolytic
C20 | NC | Capacitors_THT:C_Disc_D5.0mm_W2.5mm_P5.00mm
C21 | 10 uF | Capacitors_THT:C_Disc_D5.0mm_W2.5mm_P5.00mm | don’t populate, but if you do, X7R ceramic
C22 | 47 uF | Capacitors_THT:CP_Radial_D5.0mm_P2.50mm | don’t populate, but if you do, 25 V electrolytic
C23 | 0.1 uF | Capacitors_THT:C_Axial_L3.8mm_D2.6mm_P10.00mm_Horizontal | 100 nF, 250+V film
C24 | 0.1 uF | Capacitors_THT:C_Axial_L3.8mm_D2.6mm_P10.00mm_Horizontal | 100 nF, 250+V film
C25 | SHORT | Capacitors_THT:C_Disc_D5.0mm_W2.5mm_P5.00mm | use a wire here
D1 | 1N4752A | Diodes_THT:D_DO-41_SOD81_P7.62mm_Horizontal | 33 V zener, may need to be adjusted if rail voltage is adjusted
D2 | RED LED | LEDs:LED_D3.0mm
D3 | 1N4148 | Diodes_THT:D_DO-35_SOD27_P7.62mm_Horizontal
D4 | 1N4148 | Diodes_THT:D_DO-35_SOD27_P7.62mm_Horizontal
D5 | 1N4007 | Diodes_THT:D_DO-41_SOD81_P7.62mm_Horizontal
D6 | 1N4007 | Diodes_THT:D_DO-41_SOD81_P7.62mm_Horizontal
D7 | 1N4755A | Diodes_THT:D_DO-41_SOD81_P7.62mm_Horizontal | 43 V zener, may need to be adjusted if rail voltage is adjusted
D8 | 1N4755A | Diodes_THT:D_DO-41_SOD81_P7.62mm_Horizontal | 43 V zener, may need to be adjusted if rail voltage is adjusted
D9 | 1N4755A | Diodes_THT:D_DO-41_SOD81_P7.62mm_Horizontal | 43 V zener, may need to be adjusted if rail voltage is adjusted
D10 | 1N4755A | Diodes_THT:D_DO-41_SOD81_P7.62mm_Horizontal | 43 V zener, may need to be adjusted if rail voltage is adjusted
D11 | 1N4148 | Diodes_THT:D_DO-35_SOD27_P7.62mm_Horizontal
D12 | 1N4148 | Diodes_THT:D_DO-35_SOD27_P7.62mm_Horizontal
J1 | Conn_01x02 | poweramp:TerminalBlock_bornier-2_P5.08mm_with_spade | spade connectors
J2 | Conn_01x02 | poweramp:TerminalBlock_bornier-2_P5.08mm_with_spade | spade connectors
J3 | Conn_01x02 | poweramp:TerminalBlock_bornier-2_P5.08mm_with_spade | spade connectors
J8 | Conn_01x02 | Connectors_Terminal_Blocks:TerminalBlock_bornier-2_P5.08mm | 2 position terminal block
J9 | Conn_Coaxial | Connectors:SMA_THT_Jack_Straight | SMA female connector
JP1 | Jumper_NO_Small | Pin_Headers:Pin_Header_Straight_1x02_Pitch2.54mm | do not populate
JP2 | Jumper_NO_Small | Pin_Headers:Pin_Header_Straight_1x02_Pitch2.54mm | do not populate
L1 | 1 uH | Inductors_THT:L_Radial_D16.8mm_P11.43mm_Vishay_IHB-1 | hand wound air inductor (1 mm wire,approximately 10 turns, 20 mm diameter)
Q1 | 2N5551 | TO_SOT_Packages_THT:TO-92_Inline_Wide | can be replaced with MPSA18
Q2 | 2N5551 | TO_SOT_Packages_THT:TO-92_Inline_Wide | can be replaced with MPSA18
Q3 | 2N5401 | TO_SOT_Packages_THT:TO-92_Inline_Wide
Q4 | 2N5401 | TO_SOT_Packages_THT:TO-92_Inline_Wide
Q5 | 2N5551 | TO_SOT_Packages_THT:TO-92_Inline_Wide
Q6 | 2N5551 | TO_SOT_Packages_THT:TO-92_Inline_Wide
Q7 | 2N5551 | TO_SOT_Packages_THT:TO-92_Inline_Wide
Q8 | 2N5401 | TO_SOT_Packages_THT:TO-92_Inline_Wide
Q10 | MJE15033 | TO_SOT_Packages_THT:TO-220-3_Vertical | can be replaced with TO-126 KSA1381, but it must be reversed!
Q11 | MJE15032 | TO_SOT_Packages_THT:TO-220-3_Vertical
Q12 | MJE15032 | TO_SOT_Packages_THT:TO-220-3_Vertical | can be replaced with TO-126 KSC3503, but it must be reversed!
Q13 | 2N5551 | TO_SOT_Packages_THT:TO-92_Inline_Wide
Q14 | 2N5401 | TO_SOT_Packages_THT:TO-92_Inline_Wide
Q15 | MJE15032 | TO_SOT_Packages_THT:TO-220-3_Vertical | put kink in leads so that distance to tapped hole on heatsink can be adjusted
Q16 | MJE15033 | TO_SOT_Packages_THT:TO-220-3_Vertical | put kink in leads so that distance to tapped hole on heatsink can be adjusted
Q17 | MJL3281A | poweramp:TO-264_Vertical_w_pads | put kink in leads so that distance to tapped hole on heatsink can be adjusted
Q18 | MJL1302A | poweramp:TO-264_Vertical_w_pads | put kink in leads so that distance to tapped hole on heatsink can be adjusted
Q19 | MJL3281A | poweramp:TO-264_Vertical_w_pads | put kink in leads so that distance to tapped hole on heatsink can be adjusted
Q20 | MJL1302A | poweramp:TO-264_Vertical_w_pads | put kink in leads so that distance to tapped hole on heatsink can be adjusted
Q21 | MJL3281A | poweramp:TO-264_Vertical_w_pads | put kink in leads so that distance to tapped hole on heatsink can be adjusted
Q22 | MJL1302A | poweramp:TO-264_Vertical_w_pads | put kink in leads so that distance to tapped hole on heatsink can be adjusted
Q23 | MJL3281A | poweramp:TO-264_Vertical_w_pads | put kink in leads so that distance to tapped hole on heatsink can be adjusted
Q24 | MJL1302A | poweramp:TO-264_Vertical_w_pads | put kink in leads so that distance to tapped hole on heatsink can be adjusted
R1 | 1k | Resistors_THT:R_Axial_DIN0207_L6.3mm_D2.5mm_P7.62mm_Horizontal | ¼ watt
R2 | 10k | Resistors_THT:R_Axial_DIN0207_L6.3mm_D2.5mm_P7.62mm_Horizontal | ¼ watt
R3 | 180R | Resistors_THT:R_Axial_DIN0207_L6.3mm_D2.5mm_P7.62mm_Horizontal | ¼ watt
R4 | 180R | Resistors_THT:R_Axial_DIN0207_L6.3mm_D2.5mm_P7.62mm_Horizontal | ¼ watt
R5 | 1k | Resistors_THT:R_Axial_DIN0207_L6.3mm_D2.5mm_P7.62mm_Horizontal | ¼ watt
R6 | 100R | Resistors_THT:R_Axial_DIN0207_L6.3mm_D2.5mm_P7.62mm_Horizontal | ¼ watt
R7 | 100R | Resistors_THT:R_Axial_DIN0207_L6.3mm_D2.5mm_P7.62mm_Horizontal | ¼ watt
R8 | 56R | Resistors_THT:R_Axial_DIN0207_L6.3mm_D2.5mm_P7.62mm_Horizontal | ¼ watt
R9 | 56R | Resistors_THT:R_Axial_DIN0207_L6.3mm_D2.5mm_P7.62mm_Horizontal | ¼ watt
R10 | 100R | Potentiometers:Potentiometer_Trimmer_Bourns_3296W | 100 ohm 3296W potentiometer
R11 | 6k8 | Resistors_THT:R_Axial_DIN0411_L9.9mm_D3.6mm_P12.70mm_Horizontal | 2 or 3 watt resistor
R12 | 200R | Resistors_THT:R_Axial_DIN0207_L6.3mm_D2.5mm_P7.62mm_Horizontal | ¼ watt
R13 | 5k6 | Resistors_THT:R_Axial_DIN0411_L9.9mm_D3.6mm_P12.70mm_Horizontal | 2 or 3 watt resistor
R14 | 10k | Resistors_THT:R_Axial_DIN0207_L6.3mm_D2.5mm_P7.62mm_Horizontal | ¼ watt
R15 | 330R | Resistors_THT:R_Axial_DIN0207_L6.3mm_D2.5mm_P7.62mm_Horizontal | ¼ watt
R16 | 6k8 | Resistors_THT:R_Axial_DIN0309_L9.0mm_D3.2mm_P12.70mm_Horizontal | 2 or 3 watt resistor
R17 | 1k | Resistors_THT:R_Axial_DIN0207_L6.3mm_D2.5mm_P7.62mm_Horizontal | ¼ watt
R18 | NC | Resistors_THT:R_Axial_DIN0207_L6.3mm_D2.5mm_P7.62mm_Horizontal
R19 | 33R | Resistors_THT:R_Axial_DIN0309_L9.0mm_D3.2mm_P12.70mm_Horizontal | 2 or 3 watt resistor
R20 | 10R | Resistors_THT:R_Axial_DIN0207_L6.3mm_D2.5mm_P7.62mm_Horizontal | ¼ watt
R21 | 390R | Resistors_THT:R_Axial_DIN0207_L6.3mm_D2.5mm_P7.62mm_Horizontal | ¼ watt
R22 | 200R | Potentiometers:Potentiometer_Trimmer_Bourns_3296W | 200 ohm 3296W potentiometer
R23 | 100R | Resistors_THT:R_Axial_DIN0207_L6.3mm_D2.5mm_P7.62mm_Horizontal | ¼ watt
R24 | 120R | Resistors_THT:R_Axial_DIN0207_L6.3mm_D2.5mm_P7.62mm_Horizontal | ¼ watt
R25 | 6k8 | Resistors_THT:R_Axial_DIN0411_L9.9mm_D3.6mm_P15.24mm_Horizontal | 2 or 3 watt resistor
R26 | 33R | Resistors_THT:R_Axial_DIN0207_L6.3mm_D2.5mm_P7.62mm_Horizontal | ¼ watt
R27 | 33R | Resistors_THT:R_Axial_DIN0207_L6.3mm_D2.5mm_P7.62mm_Horizontal | ¼ watt
R28 | 6k8 | Resistors_THT:R_Axial_DIN0411_L9.9mm_D3.6mm_P15.24mm_Horizontal | 2 or 3 watt resistor
R29 | 120R | Resistors_THT:R_Axial_DIN0207_L6.3mm_D2.5mm_P7.62mm_Horizontal | ¼ watt
R30 | 120R | Resistors_THT:R_Axial_DIN0207_L6.3mm_D2.5mm_P7.62mm_Horizontal | ¼ watt
R31 | 33R | Resistors_THT:R_Axial_DIN0411_L9.9mm_D3.6mm_P12.70mm_Horizontal | 2 or 3 watt resistor
R32 | 33R | Resistors_THT:R_Axial_DIN0411_L9.9mm_D3.6mm_P12.70mm_Horizontal | 2 or 3 watt resistor
R33 | 0R39 | Resistors_THT:R_Axial_DIN0614_L14.3mm_D5.7mm_P20.32mm_Horizontal | 5 watt sandblock or metal oxide resistor
R34 | 0R39 | Resistors_THT:R_Axial_DIN0614_L14.3mm_D5.7mm_P20.32mm_Horizontal | 5 watt sandblock or metal oxide resistor
R35 | 0R39 | Resistors_THT:R_Axial_DIN0614_L14.3mm_D5.7mm_P20.32mm_Horizontal | 5 watt sandblock or metal oxide resistor
R36 | 0R39 | Resistors_THT:R_Axial_DIN0614_L14.3mm_D5.7mm_P20.32mm_Horizontal | 5 watt sandblock or metal oxide resistor
R37 | 0R39 | Resistors_THT:R_Axial_DIN0614_L14.3mm_D5.7mm_P20.32mm_Horizontal | 5 watt sandblock or metal oxide resistor
R38 | 0R39 | Resistors_THT:R_Axial_DIN0614_L14.3mm_D5.7mm_P20.32mm_Horizontal | 5 watt sandblock or metal oxide resistor
R39 | 0R39 | Resistors_THT:R_Axial_DIN0614_L14.3mm_D5.7mm_P20.32mm_Horizontal | 5 watt sandblock or metal oxide resistor
R40 | 0R39 | Resistors_THT:R_Axial_DIN0614_L14.3mm_D5.7mm_P20.32mm_Horizontal | 5 watt sandblock or metal oxide resistor
R41 | 4R7 | Resistors_THT:R_Axial_DIN0309_L9.0mm_D3.2mm_P12.70mm_Horizontal | 2 or 3 watt resistor
R42 | 4R7 | Resistors_THT:R_Axial_DIN0411_L9.9mm_D3.6mm_P15.24mm_Horizontal | 2 or 3 watt resistor
R43 | 10k | Resistors_THT:R_Axial_DIN0309_L9.0mm_D3.2mm_P12.70mm_Horizontal | 2 or 3 watt resistor
R44 | 1R | Resistors_THT:R_Axial_DIN0411_L9.9mm_D3.6mm_P15.24mm_Horizontal | 1 watt resistor
R45 | 1R | Resistors_THT:R_Axial_DIN0411_L9.9mm_D3.6mm_P15.24mm_Horizontal | 1 watt resistor
R46 | 1R | Resistors_THT:R_Axial_DIN0411_L9.9mm_D3.6mm_P15.24mm_Horizontal | 1 watt resistor
R47 | 1R | Resistors_THT:R_Axial_DIN0411_L9.9mm_D3.6mm_P15.24mm_Horizontal | 1 watt resistor
R48 | 1R | Resistors_THT:R_Axial_DIN0411_L9.9mm_D3.6mm_P15.24mm_Horizontal | 1 watt resistor
R49 | 1R | Resistors_THT:R_Axial_DIN0411_L9.9mm_D3.6mm_P15.24mm_Horizontal | 1 watt resistor
R50 | 1R | Resistors_THT:R_Axial_DIN0411_L9.9mm_D3.6mm_P15.24mm_Horizontal | 1 watt resistor
R51 | 1R | Resistors_THT:R_Axial_DIN0411_L9.9mm_D3.6mm_P15.24mm_Horizontal | 1 watt resistor

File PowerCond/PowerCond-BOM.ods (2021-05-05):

Source: | E:/Poweramp/PowerCond/PowerCond.sch
Date: | 1/3/2021 2:53:29 PM
Tool: | Eeschema 4.0.7
Component Count: | 62
Ref | Value | Footprint | Source | PN
C1 | 1 uF | Capacitors_THT:C_Axial_L5.1mm_D3.1mm_P12.50mm_Horizontal | LCSC | C178471
C2 | 1 uF | Capacitors_THT:C_Axial_L5.1mm_D3.1mm_P12.50mm_Horizontal | LCSC | C178471
C5 | 1 uF | Capacitors_THT:C_Axial_L5.1mm_D3.1mm_P12.50mm_Horizontal | LCSC | C178471
C6 | 1 uF | Capacitors_THT:C_Axial_L5.1mm_D3.1mm_P12.50mm_Horizontal | LCSC | C178471
C7 | 1 uF | Capacitors_THT:C_Axial_L5.1mm_D3.1mm_P12.50mm_Horizontal | LCSC | C178471
C8 | 1 uF | Capacitors_THT:C_Axial_L5.1mm_D3.1mm_P12.50mm_Horizontal | LCSC | C178471
C9 | 100 uF | Capacitors_THT:CP_Radial_D14.0mm_P7.50mm | LCSC | C308838
C10 | 100 uF | Capacitors_THT:CP_Radial_D14.0mm_P7.50mm | LCSC | C308838
C11 | 100 uF | Capacitors_THT:CP_Radial_D14.0mm_P7.50mm | LCSC | C308838
C12 | 100 uF | Capacitors_THT:CP_Radial_D14.0mm_P7.50mm | LCSC | C308838
C13 | 100 uF | Capacitors_THT:CP_Radial_D14.0mm_P7.50mm | LCSC | C308838
C14 | 100 uF | Capacitors_THT:CP_Radial_D14.0mm_P7.50mm | LCSC | C308838
C15 | 1 uF | Capacitors_THT:C_Axial_L5.1mm_D3.1mm_P12.50mm_Horizontal | LCSC | C178471
C16 | 1 uF | Capacitors_THT:C_Axial_L5.1mm_D3.1mm_P12.50mm_Horizontal | LCSC | C178471
C17 | 1 nF | Capacitors_THT:C_Disc_D5.0mm_W2.5mm_P5.00mm | LCSC | C377843
C18 | 1 nF | Capacitors_THT:C_Disc_D5.0mm_W2.5mm_P5.00mm | LCSC | C377843
C19 | 1 nF | Capacitors_THT:C_Disc_D5.0mm_W2.5mm_P5.00mm | LCSC | C377843
C20 | 1 nF | Capacitors_THT:C_Disc_D5.0mm_W2.5mm_P5.00mm | LCSC | C377843
C21 | 1 nF | Capacitors_THT:C_Disc_D5.0mm_W2.5mm_P5.00mm | LCSC | C377843
C22 | 1 nF | Capacitors_THT:C_Disc_D5.0mm_W2.5mm_P5.00mm | LCSC | C377843
C23 | 1 nF | Capacitors_THT:C_Disc_D5.0mm_W2.5mm_P5.00mm | LCSC | C377843
C24 | 1 nF | Capacitors_THT:C_Disc_D5.0mm_W2.5mm_P5.00mm | LCSC | C377843
C25 | 1 uF | Capacitors_THT:C_Axial_L5.1mm_D3.1mm_P12.50mm_Horizontal | LCSC | C178471
C26 | 1 uF | Capacitors_THT:C_Axial_L5.1mm_D3.1mm_P12.50mm_Horizontal | LCSC | C178471
C27 | 1 nF | Capacitors_THT:C_Disc_D5.0mm_W2.5mm_P5.00mm | LCSC | C377843
C28 | 1 nF | Capacitors_THT:C_Disc_D5.0mm_W2.5mm_P5.00mm | LCSC | C377843
C29 | 1 uF | Capacitors_THT:C_Axial_L5.1mm_D3.1mm_P12.50mm_Horizontal | LCSC | C178471
C30 | 1 uF | Capacitors_THT:C_Axial_L5.1mm_D3.1mm_P12.50mm_Horizontal | LCSC | C178471
C31 | 1 nF | Capacitors_THT:C_Disc_D5.0mm_W2.5mm_P5.00mm | LCSC | C377843
C32 | 1 nF | Capacitors_THT:C_Disc_D5.0mm_W2.5mm_P5.00mm | LCSC | C377843
D1 | 10A10 | Diodes_THT:D_P600_R-6_P12.70mm_Horizontal | LCSC | C106904
D2 | 10A10 | Diodes_THT:D_P600_R-6_P12.70mm_Horizontal | LCSC | C106904
D3 | 10A10 | Diodes_THT:D_P600_R-6_P12.70mm_Horizontal | LCSC | C106904
D4 | 10A10 | Diodes_THT:D_P600_R-6_P12.70mm_Horizontal | LCSC | C106904
D5 | 1N4755A | Diodes_THT:D_DO-41_SOD81_P7.62mm_Horizontal | LCSC | C8044
D6 | 1N4755A | Diodes_THT:D_DO-41_SOD81_P7.62mm_Horizontal | LCSC | C8044
D7 | 1N4755A | Diodes_THT:D_DO-41_SOD81_P7.62mm_Horizontal | LCSC | C8044
D8 | 1N4755A | Diodes_THT:D_DO-41_SOD81_P7.62mm_Horizontal | LCSC | C8044
D9 | 1N4755A | Diodes_THT:D_DO-41_SOD81_P7.62mm_Horizontal | LCSC | C8044
D10 | 1N4755A | Diodes_THT:D_DO-41_SOD81_P7.62mm_Horizontal | LCSC | C8044
D11 | 1N4755A | Diodes_THT:D_DO-41_SOD81_P7.62mm_Horizontal | LCSC | C8044
D12 | 1N4755A | Diodes_THT:D_DO-41_SOD81_P7.62mm_Horizontal | LCSC | C8044
J1 | Conn_01x02 | PowerCond:TerminalBlock_bornier-2_P5.08mm_with_spade | LCSC | C52878
J2 | Conn_01x02 | PowerCond:TerminalBlock_bornier-2_P5.08mm_with_spade | LCSC | C52878
J3 | Conn_01x02 | PowerCond:TerminalBlock_bornier-2_P5.08mm_with_spade | LCSC | C52878
J4 | Conn_01x02 | PowerCond:TerminalBlock_bornier-2_P5.08mm_with_spade | LCSC | C52878
J5 | Conn_01x02 | PowerCond:TerminalBlock_bornier-2_P5.08mm_with_spade | LCSC | C52878
J6 | Conn_01x02 | PowerCond:TerminalBlock_bornier-2_P5.08mm_with_spade | LCSC | C52878
J7 | Conn_01x02 | PowerCond:TerminalBlock_bornier-2_P5.08mm_with_spade | LCSC | C52878
J8 | Conn_01x02 | PowerCond:TerminalBlock_bornier-2_P5.08mm_with_spade | LCSC | C52878
JP1 | Jumper_NC_Small | Pin_Headers:Pin_Header_Straight_1x02_Pitch2.54mm
JP2 | Jumper_NC_Small | Pin_Headers:Pin_Header_Straight_1x02_Pitch2.54mm
R1 | 220k | Resistors_THT:R_Axial_DIN0309_L9.0mm_D3.2mm_P12.70mm_Horizontal | LCSC | C82511
R2 | 220k | Resistors_THT:R_Axial_DIN0309_L9.0mm_D3.2mm_P12.70mm_Horizontal | LCSC | C82511
T1 | Transformer_1P1Sdotted | PowerCond:GenericCMCL3 | Need green toroid
T2 | Transformer_1P1Sdotted | PowerCond:GenericCMCL3 | Need green toroid
T3 | Transformer_1P1Sdotted | PowerCond:GenericCMCL3 | Need green toroid
T4 | Transformer_1P1Sdotted | PowerCond:GenericCMCL3 | Need green toroid

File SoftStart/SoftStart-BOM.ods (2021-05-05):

Source: | E:/Poweramp/SoftStart/SoftStart.sch
Date: | 1/3/2021 2:54:01 PM
Tool: | Eeschema 4.0.7
Component Count: | 33
Ref | Value | Footprint | Source | PN
C1 | 10 nF | Capacitors_THT:C_Rect_L11.5mm_W4.5mm_P10.00mm_MKT | LCSC | C342770
C2 | 1 uF | Capacitors_THT:C_Rect_L24.0mm_W10.1mm_P22.50mm_MKT | LCSC | C390065
C3 | 1000 uF | Capacitors_THT:CP_Radial_D10.0mm_P5.00mm | LCSC | C338226
D1 | 1N4007 | Diodes_THT:D_DO-41_SOD81_P7.62mm_Horizontal | LCSC | C106903
D2 | 1N4007 | Diodes_THT:D_DO-41_SOD81_P7.62mm_Horizontal | LCSC | C106903
D3 | 1N4007 | Diodes_THT:D_DO-41_SOD81_P7.62mm_Horizontal | LCSC | C106903
D4 | 1N4007 | Diodes_THT:D_DO-41_SOD81_P7.62mm_Horizontal | LCSC | C106903
D5 | 1N4749 | Diodes_THT:D_DO-41_SOD81_P7.62mm_Horizontal | LCSC | C2552
D6 | LED | LEDs:LED_D3.0mm | LCSC | C99771
D7 | 1N4742 | Diodes_THT:D_DO-41_SOD81_P7.62mm_Horizontal | LCSC | C36751
D8 | 1N4742 | Diodes_THT:D_DO-41_SOD81_P7.62mm_Horizontal | LCSC | C36751
J11 | Conn_01x02 | Connectors_Terminal_Blocks:TerminalBlock_bornier-2_P5.08mm | LCSC | C8461
R1 | 220R | Resistors_THT:R_Axial_Power_L20.0mm_W6.4mm_P22.40mm | LCSC | C334296
R2 | 2k2 | Resistors_THT:R_Axial_DIN0207_L6.3mm_D2.5mm_P7.62mm_Horizontal | LCSC | C58595
R3 | 150R | Resistors_THT:R_Axial_Power_L20.0mm_W6.4mm_P22.40mm | LCSC | C334292
R4 | 150R | Resistors_THT:R_Axial_Power_L20.0mm_W6.4mm_P22.40mm | LCSC | C334292
R5 | 150R | Resistors_THT:R_Axial_Power_L20.0mm_W6.4mm_P22.40mm | LCSC | C334292
R6 | 150R | Resistors_THT:R_Axial_Power_L20.0mm_W6.4mm_P22.40mm | LCSC | C334292
R7 | 1M | Resistors_THT:R_Axial_DIN0207_L6.3mm_D2.5mm_P7.62mm_Horizontal | LCSC | C58596
RLY1 | SPDTRelay | SoftStart:SMIHRelay | LCSC | C231361
RLY2 | SPDTRelay | SoftStart:SMIHRelay | LCSC | C45534

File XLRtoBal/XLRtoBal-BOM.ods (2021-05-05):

Source: | E:/Poweramp/XLRtoBal/XLRtoBal.sch
Date: | 1/3/2021 2:54:26 PM
Tool: | Eeschema 4.0.7
Component Count: | 60
Ref | Value | Footprint | Source | PN
C1 | 470 pF | Capacitors_THT:C_Disc_D5.0mm_W2.5mm_P5.00mm | Digikey | 445-174271-1-ND
C2 | 470 pF | Capacitors_THT:C_Disc_D5.0mm_W2.5mm_P5.00mm | Digikey | 445-174271-1-ND
C3 | 100 pF | Capacitors_THT:C_Disc_D5.0mm_W2.5mm_P5.00mm | LCSC | 445-181203-ND
C4 | 100 nF | Capacitors_THT:C_Disc_D5.0mm_W2.5mm_P5.00mm | LCSC | C254109
C5 | 220 uF | Capacitors_THT:CP_Radial_D8.0mm_P5.00mm | LCSC | C239308
C6 | 100 nF | Capacitors_THT:C_Disc_D5.0mm_W2.5mm_P5.00mm | LCSC | C254109
C7 | 100 nF | Capacitors_THT:C_Disc_D5.0mm_W2.5mm_P5.00mm | LCSC | C254109
C8 | 100 uF | Capacitors_THT:CP_Radial_D10.0mm_P5.00mm | LCSC | C125770
C9 | 100 uF | Capacitors_THT:CP_Radial_D10.0mm_P5.00mm | LCSC | C125770
C10 | 100 nF | Capacitors_THT:C_Disc_D5.0mm_W2.5mm_P5.00mm | LCSC | C254109
C11 | 100 nF | Capacitors_THT:C_Disc_D5.0mm_W2.5mm_P5.00mm | LCSC | C254109
C12 | 100 nF | Capacitors_THT:C_Disc_D5.0mm_W2.5mm_P5.00mm | LCSC | C254109
C13 | 470 pF | Capacitors_THT:C_Disc_D5.0mm_W2.5mm_P5.00mm | Digikey | 445-174271-1-ND
C14 | 470 pF | Capacitors_THT:C_Disc_D5.0mm_W2.5mm_P5.00mm | Digikey | 445-174271-1-ND
C15 | 100 pF | Capacitors_THT:C_Disc_D5.0mm_W2.5mm_P5.00mm | LCSC | 445-181203-ND
C16 | 100 nF | Capacitors_THT:C_Disc_D5.0mm_W2.5mm_P5.00mm | LCSC | C254109
C17 | 220 uF | Capacitors_THT:CP_Radial_D8.0mm_P5.00mm | LCSC | C239308
C18 | 100 nF | Capacitors_THT:C_Disc_D5.0mm_W2.5mm_P5.00mm | LCSC | C254109
D1 | 1N4148 | Diodes_THT:D_DO-35_SOD27_P7.62mm_Horizontal | LCSC | C14516
D2 | 1N4148 | Diodes_THT:D_DO-35_SOD27_P7.62mm_Horizontal | LCSC | C14516
D3 | 1N4148 | Diodes_THT:D_DO-35_SOD27_P7.62mm_Horizontal | LCSC | C14516
D4 | 1N4148 | Diodes_THT:D_DO-35_SOD27_P7.62mm_Horizontal | LCSC | C14516
D5 | 1N4742 | Diodes_THT:D_DO-41_SOD81_P7.62mm_Horizontal | LCSC | C36751
D6 | 1N4742 | Diodes_THT:D_DO-41_SOD81_P7.62mm_Horizontal | LCSC | C36751
D7 | 1N4148 | Diodes_THT:D_DO-35_SOD27_P7.62mm_Horizontal | LCSC | C14516
D8 | 1N4148 | Diodes_THT:D_DO-35_SOD27_P7.62mm_Horizontal | LCSC | C14516
D9 | 1N4148 | Diodes_THT:D_DO-35_SOD27_P7.62mm_Horizontal | LCSC | C14516
D10 | 1N4148 | Diodes_THT:D_DO-35_SOD27_P7.62mm_Horizontal | LCSC | C14516
D11 | LED | LEDs:LED_D3.0mm | LCSC | C99771
D12 | LED | LEDs:LED_D3.0mm | LCSC | C99771
J1 | XLR4BODYPIN |  | Digikey | 1937-1146-ND
J2 | Conn_01x04 | Connectors_Terminal_Blocks:TerminalBlock_bornier-4_P5.08mm | LCSC | C395849
J3 | Conn_01x04 | XLRtoBal:TerminalBlock_bornier-4_P5.08mm_with_spade | LCSC | C52878
J4 | XLR4BODYPIN |  | Digikey | 1937-1146-ND
J5 | Conn_01x04 | Connectors_Terminal_Blocks:TerminalBlock_bornier-4_P5.08mm | LCSC | C395849
J10 | SMAPCB | Connectors:SMA_THT_Jack_Straight | LCSC | C496549
J11 | SMAPCB | Connectors:SMA_THT_Jack_Straight | LCSC | C496549
J12 | Conn_01x02 | XLRtoBal:TerminalBlock_bornier-2_P5.08mm_with_spade | LCSC | C52878
JP1 | Jumper_NO_Small | Pin_Headers:Pin_Header_Straight_1x02_Pitch2.54mm
JP2 | Jumper_NO_Small | Pin_Headers:Pin_Header_Straight_1x02_Pitch2.54mm
JP3 | Jumper_NO_Small | Pin_Headers:Pin_Header_Straight_1x02_Pitch2.54mm
JP4 | Jumper_NO_Small | Pin_Headers:Pin_Header_Straight_1x02_Pitch2.54mm
Q1 | TIP41C | TO_SOT_Packages_THT:TO-220-3_Vertical | LCSC | C358526
Q2 | TIP42C | TO_SOT_Packages_THT:TO-220-3_Vertical | LCSC | C358527
R1 | 100R | Resistors_THT:R_Axial_DIN0207_L6.3mm_D2.5mm_P7.62mm_Horizontal | LCSC | C57438
R2 | 100R | Resistors_THT:R_Axial_DIN0207_L6.3mm_D2.5mm_P7.62mm_Horizontal | LCSC | C57438
R3 | 6k8 | Resistors_THT:R_Axial_DIN0309_L9.0mm_D3.2mm_P12.70mm_Horizontal | Digikey | A131658CT-ND
R4 | 6k8 | Resistors_THT:R_Axial_DIN0309_L9.0mm_D3.2mm_P12.70mm_Horizontal | Digikey | A131658CT-ND
R5 | 2k2 | Resistors_THT:R_Axial_DIN0207_L6.3mm_D2.5mm_P7.62mm_Horizontal | LCSC | C58595
R6 | 2k2 | Resistors_THT:R_Axial_DIN0207_L6.3mm_D2.5mm_P7.62mm_Horizontal | LCSC | C58595
R7 | 100R | Resistors_THT:R_Axial_DIN0207_L6.3mm_D2.5mm_P7.62mm_Horizontal | LCSC | C57438
R8 | 100R | Resistors_THT:R_Axial_DIN0207_L6.3mm_D2.5mm_P7.62mm_Horizontal | LCSC | C57438
R9 | 4k7 | Resistors_THT:R_Axial_DIN0207_L6.3mm_D2.5mm_P7.62mm_Horizontal | LCSC | C57204
R10 | 4k7 | Resistors_THT:R_Axial_DIN0207_L6.3mm_D2.5mm_P7.62mm_Horizontal | LCSC | C57204
U1 | THAT1200 | Housings_DIP:DIP-8_W7.62mm_Socket | Mouser | 887-1200P08-U
U2 | THAT1200 | Housings_DIP:DIP-8_W7.62mm_Socket | Mouser | 887-1200P08-U

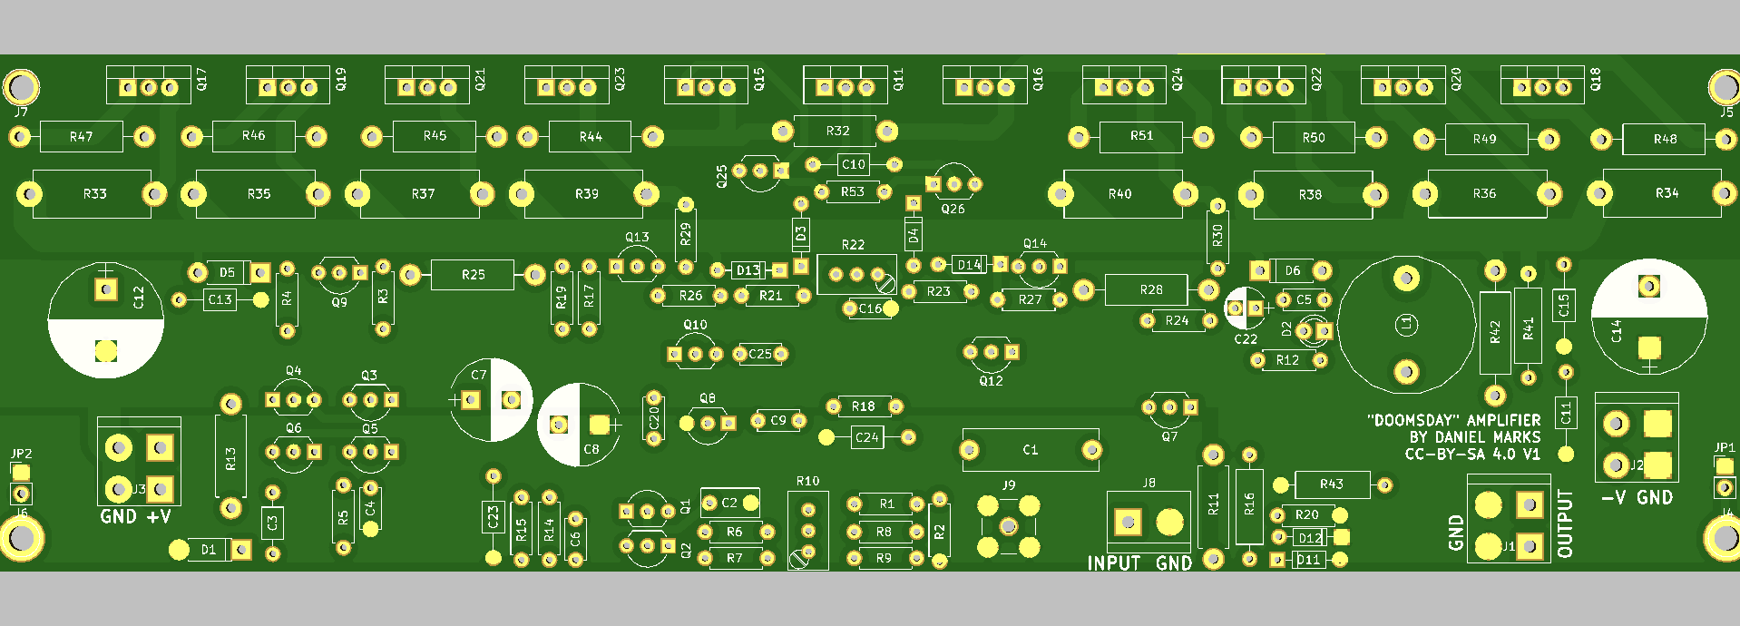
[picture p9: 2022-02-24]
PowerampSimpleParts/PowerampC300.png

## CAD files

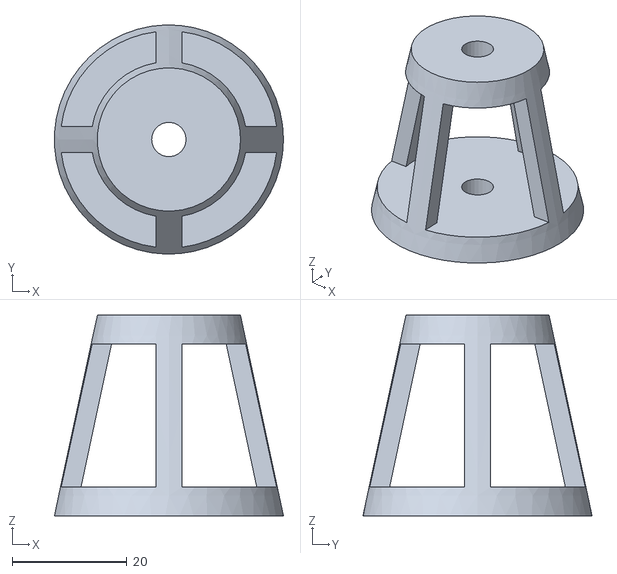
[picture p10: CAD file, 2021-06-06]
CAD/tapguide-TotalTapBody-6mm.stl
40.0 x 40.0 x 35.0

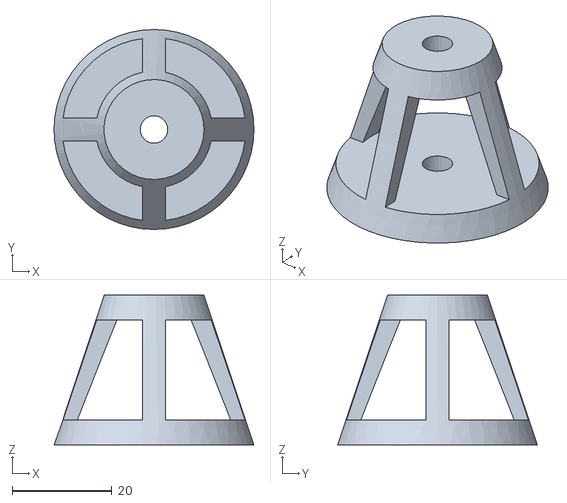
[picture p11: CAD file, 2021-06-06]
CAD/tapguide-TotalTapBody-5.5mm.stl
40.0 x 40.0 x 30.0

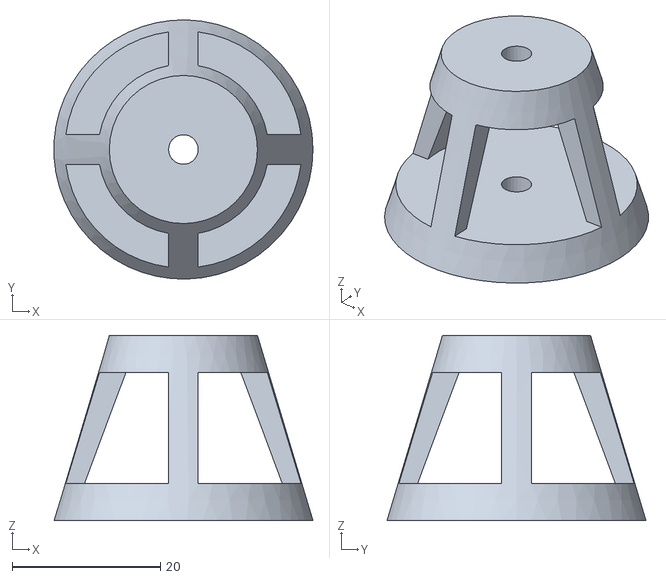
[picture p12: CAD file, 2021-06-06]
CAD/tapguide-TotalTapBody-4mm.stl
35.0 x 35.0 x 25.0

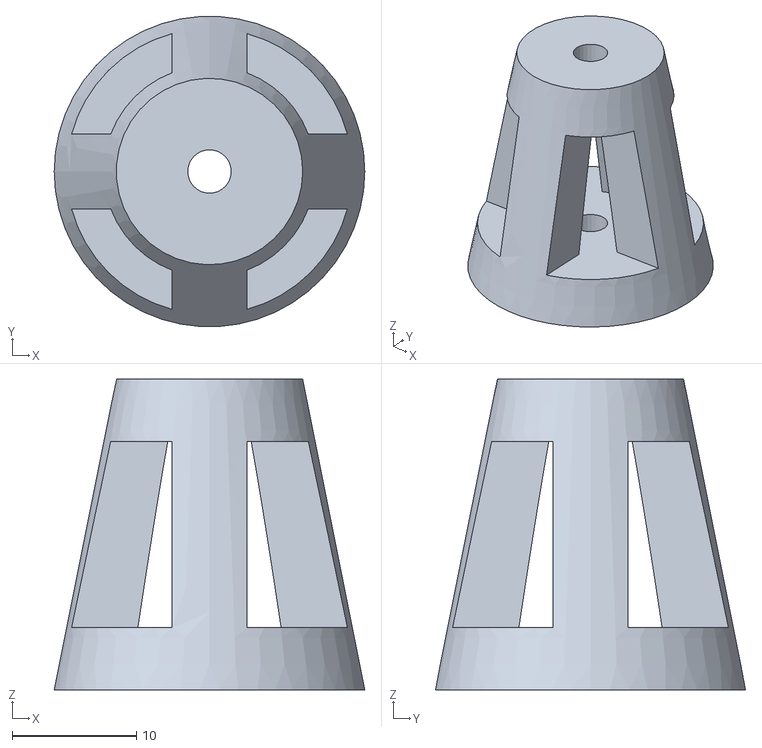
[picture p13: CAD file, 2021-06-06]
CAD/tapguide-TotalTapBody-3.5mm.stl
25.0 x 25.0 x 25.0

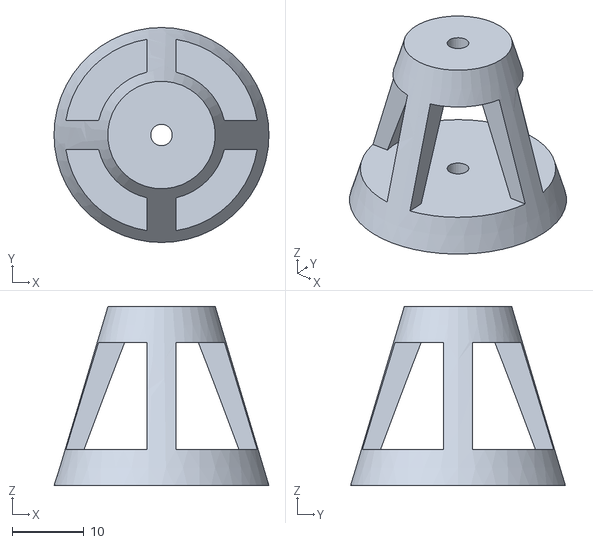
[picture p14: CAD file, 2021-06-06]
CAD/tapguide-TotalTapBody-3mm.stl
30.0 x 30.0 x 25.0

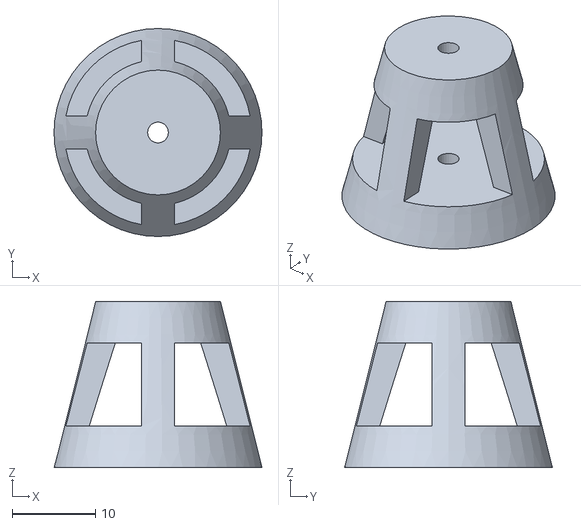
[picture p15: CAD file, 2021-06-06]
CAD/tapguide-TotalTapBody-2.5mm.stl
25.0 x 25.0 x 20.0

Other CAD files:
CAD/tapguide-TotalTapBody-7mm.stl
CAD/tapguide-TotalTapBody-5mm.stl
CAD/tapguide-TotalTapBody-4.5mm.stl
CAD/tapguide-TotalTapBody-6.5mm.stl
CAD/tapguide-TotalTapBody-2mm.stl
CAD/tapguide.FCStd

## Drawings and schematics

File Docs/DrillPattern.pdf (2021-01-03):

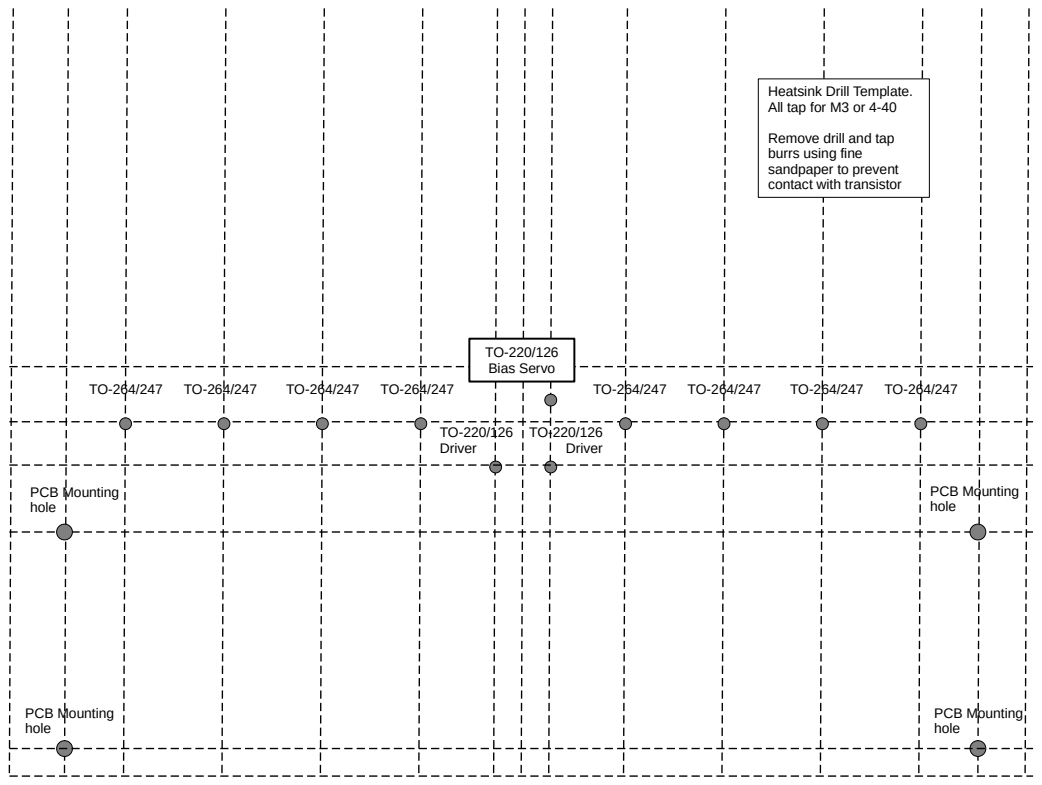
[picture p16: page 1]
TO-220/126 Driver; PCB Mounting hole; TO-220/126 Bias Servo

Heatsink Drill Template.
All tap for M3 or 4-40

Remove drill and tap
burrs using fine
sandpaper to prevent
contact with transistor

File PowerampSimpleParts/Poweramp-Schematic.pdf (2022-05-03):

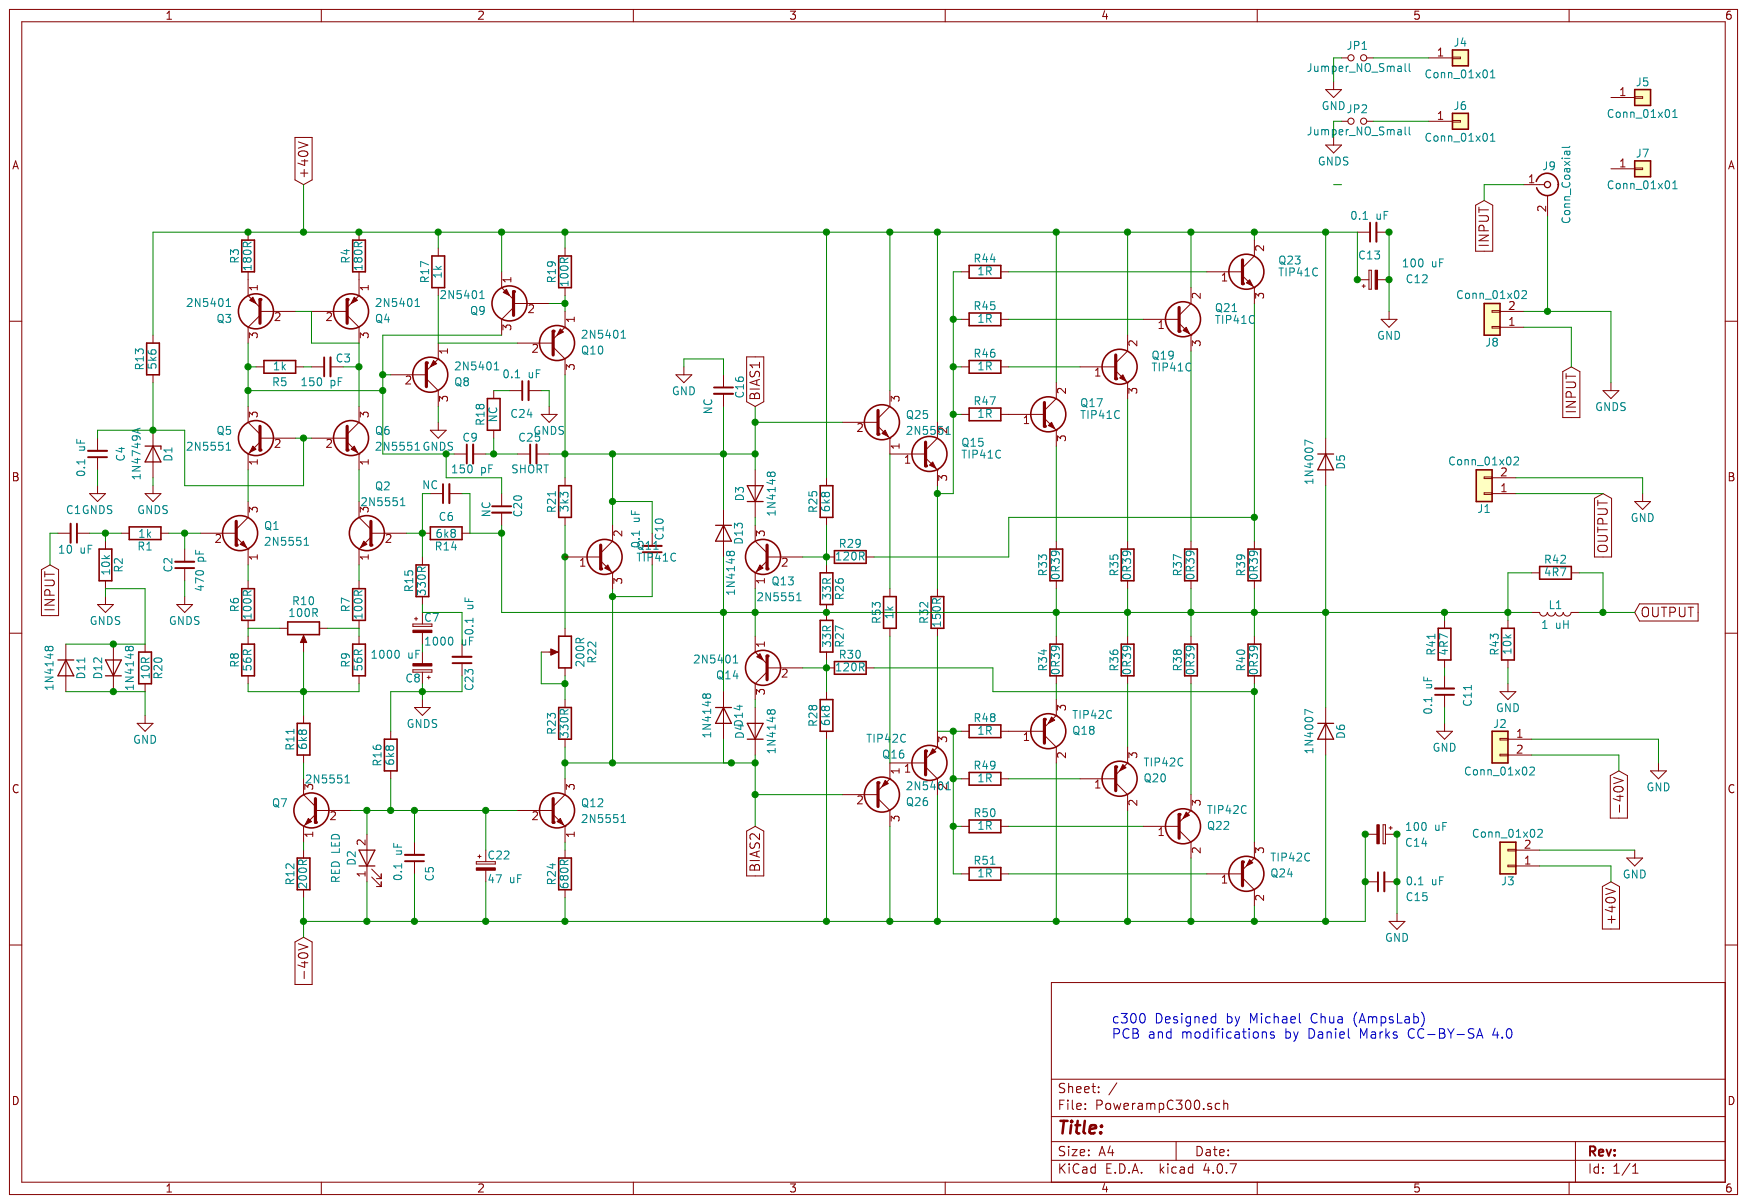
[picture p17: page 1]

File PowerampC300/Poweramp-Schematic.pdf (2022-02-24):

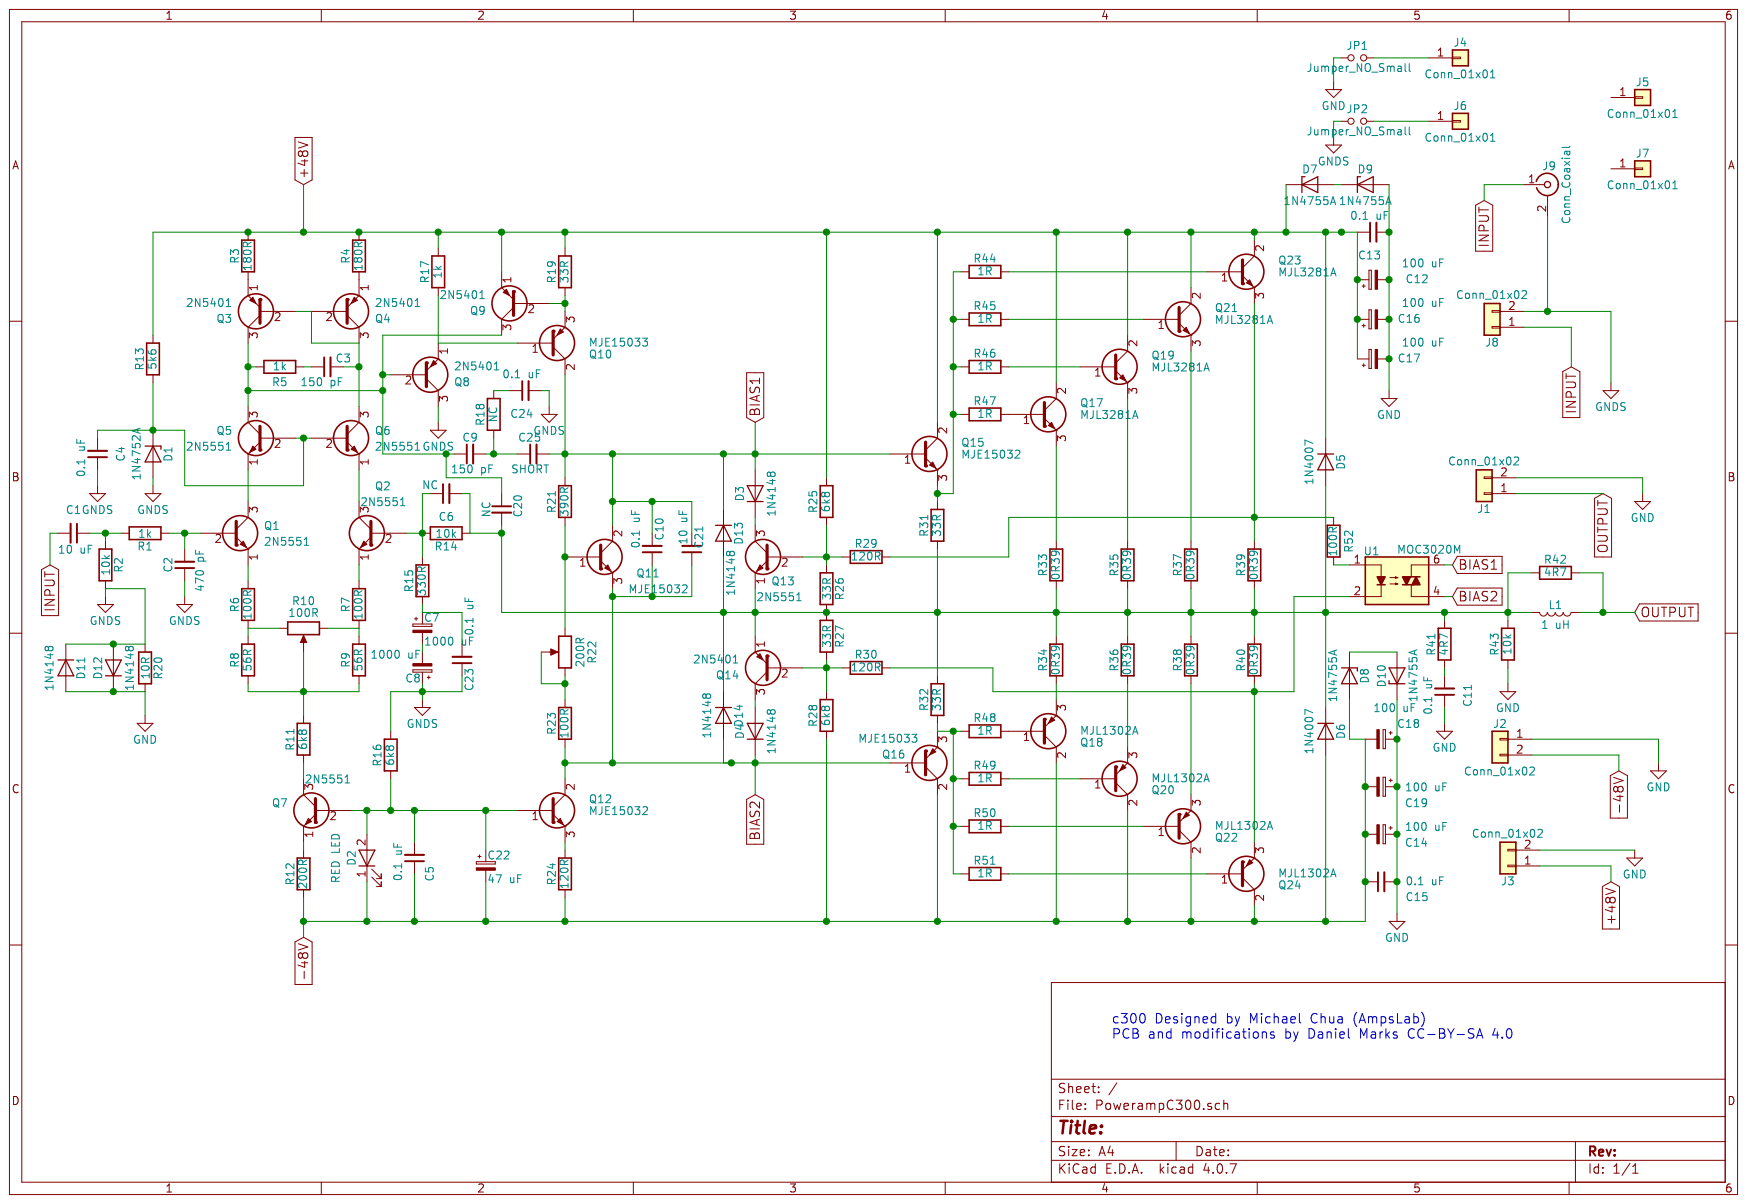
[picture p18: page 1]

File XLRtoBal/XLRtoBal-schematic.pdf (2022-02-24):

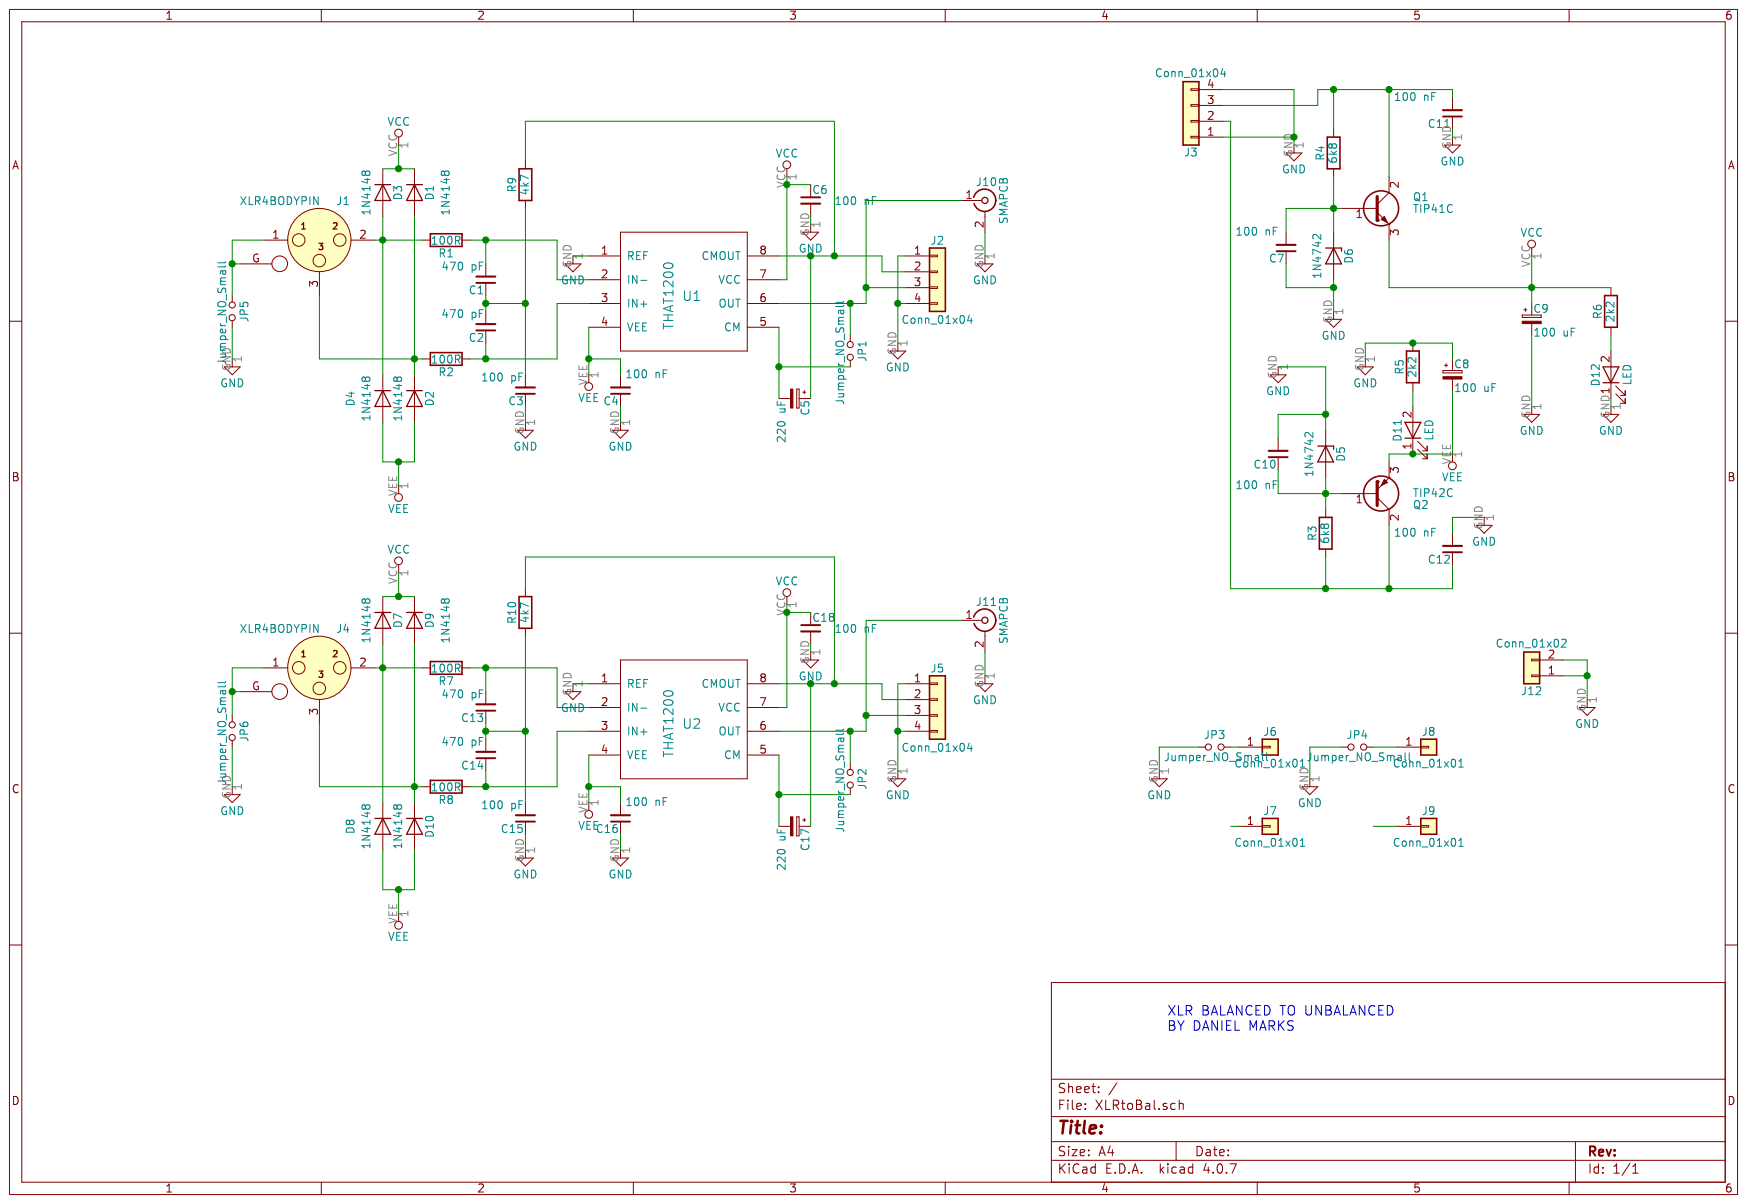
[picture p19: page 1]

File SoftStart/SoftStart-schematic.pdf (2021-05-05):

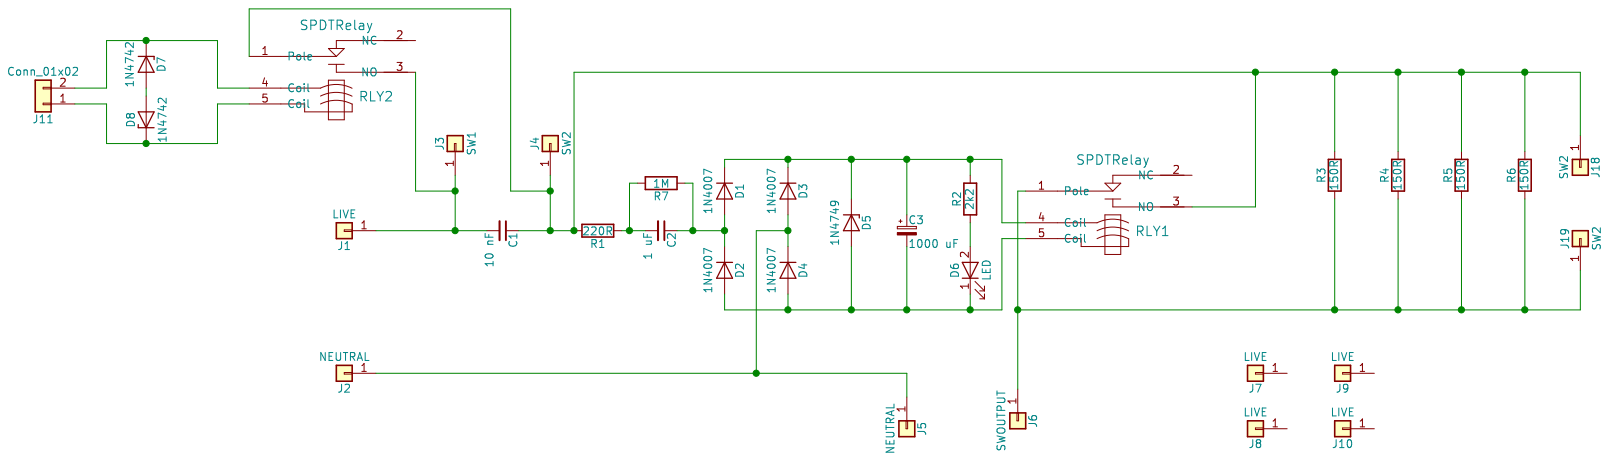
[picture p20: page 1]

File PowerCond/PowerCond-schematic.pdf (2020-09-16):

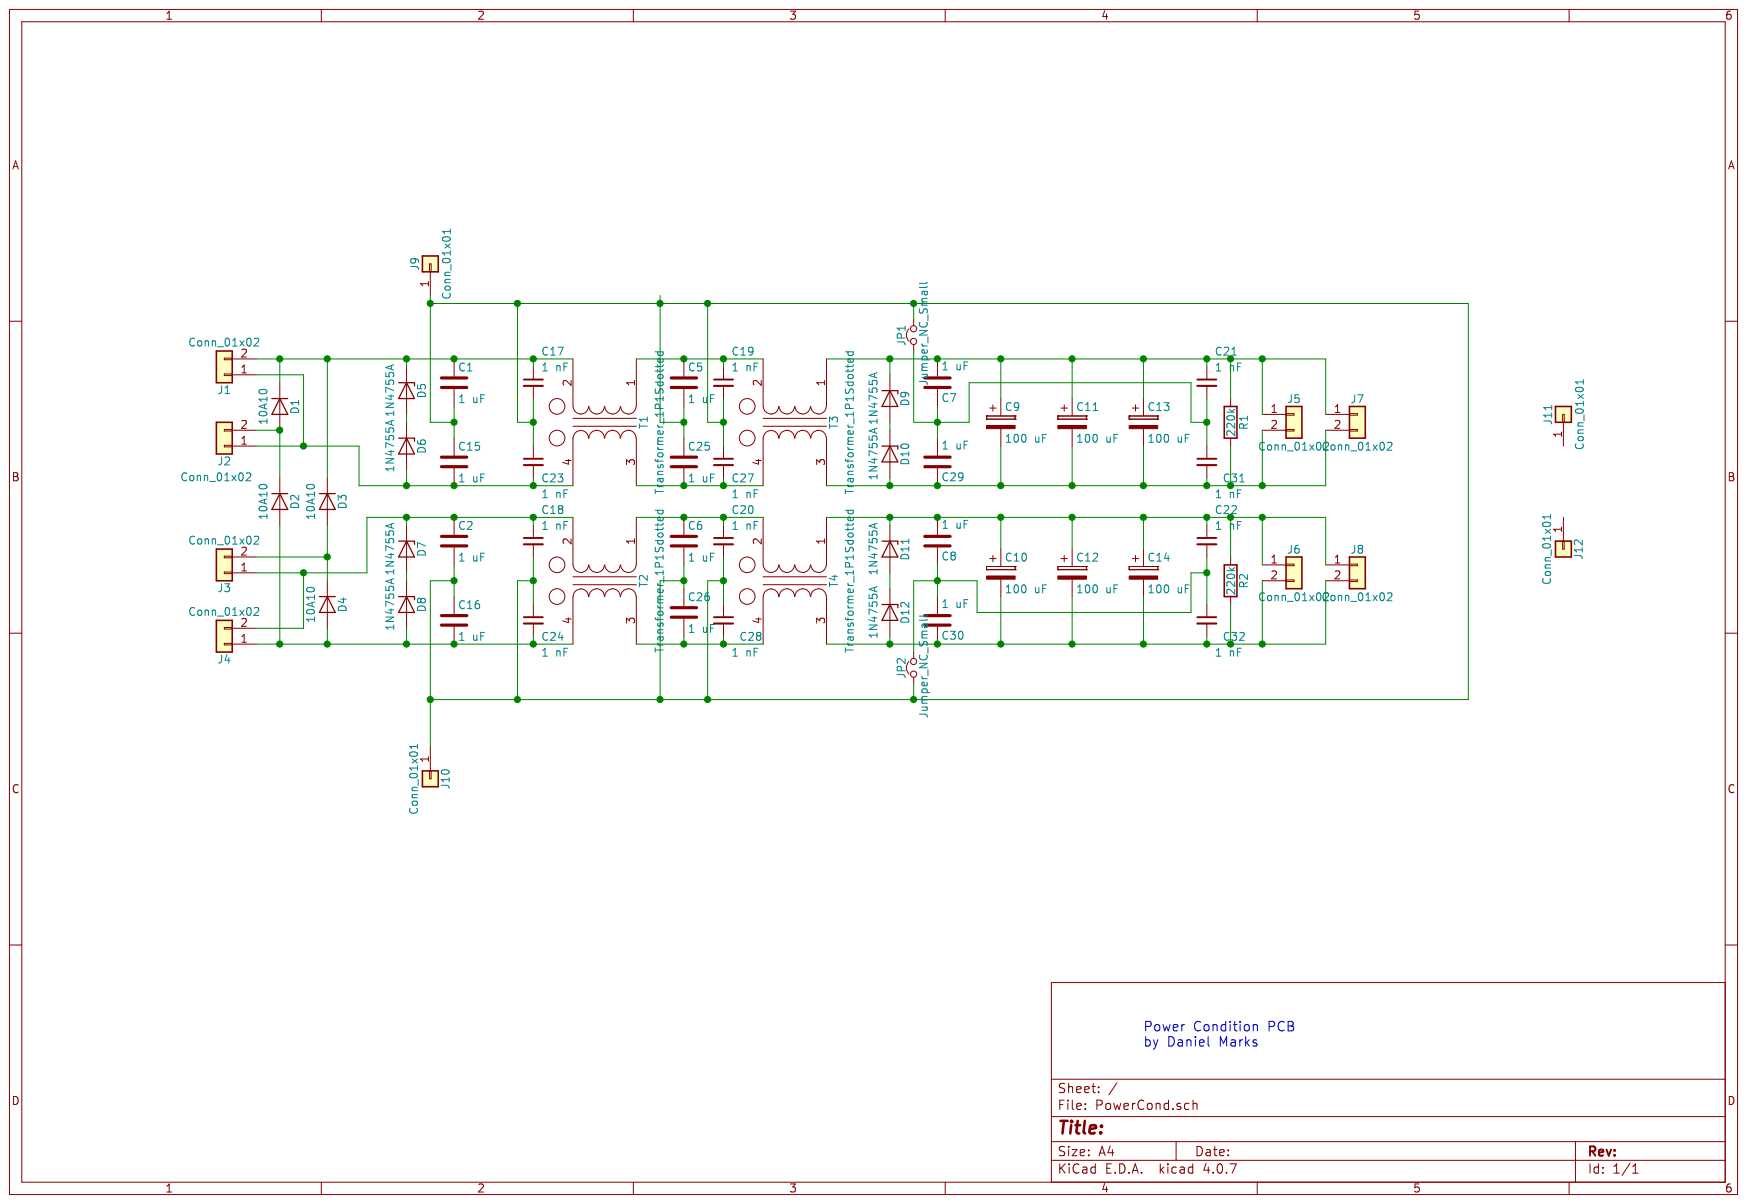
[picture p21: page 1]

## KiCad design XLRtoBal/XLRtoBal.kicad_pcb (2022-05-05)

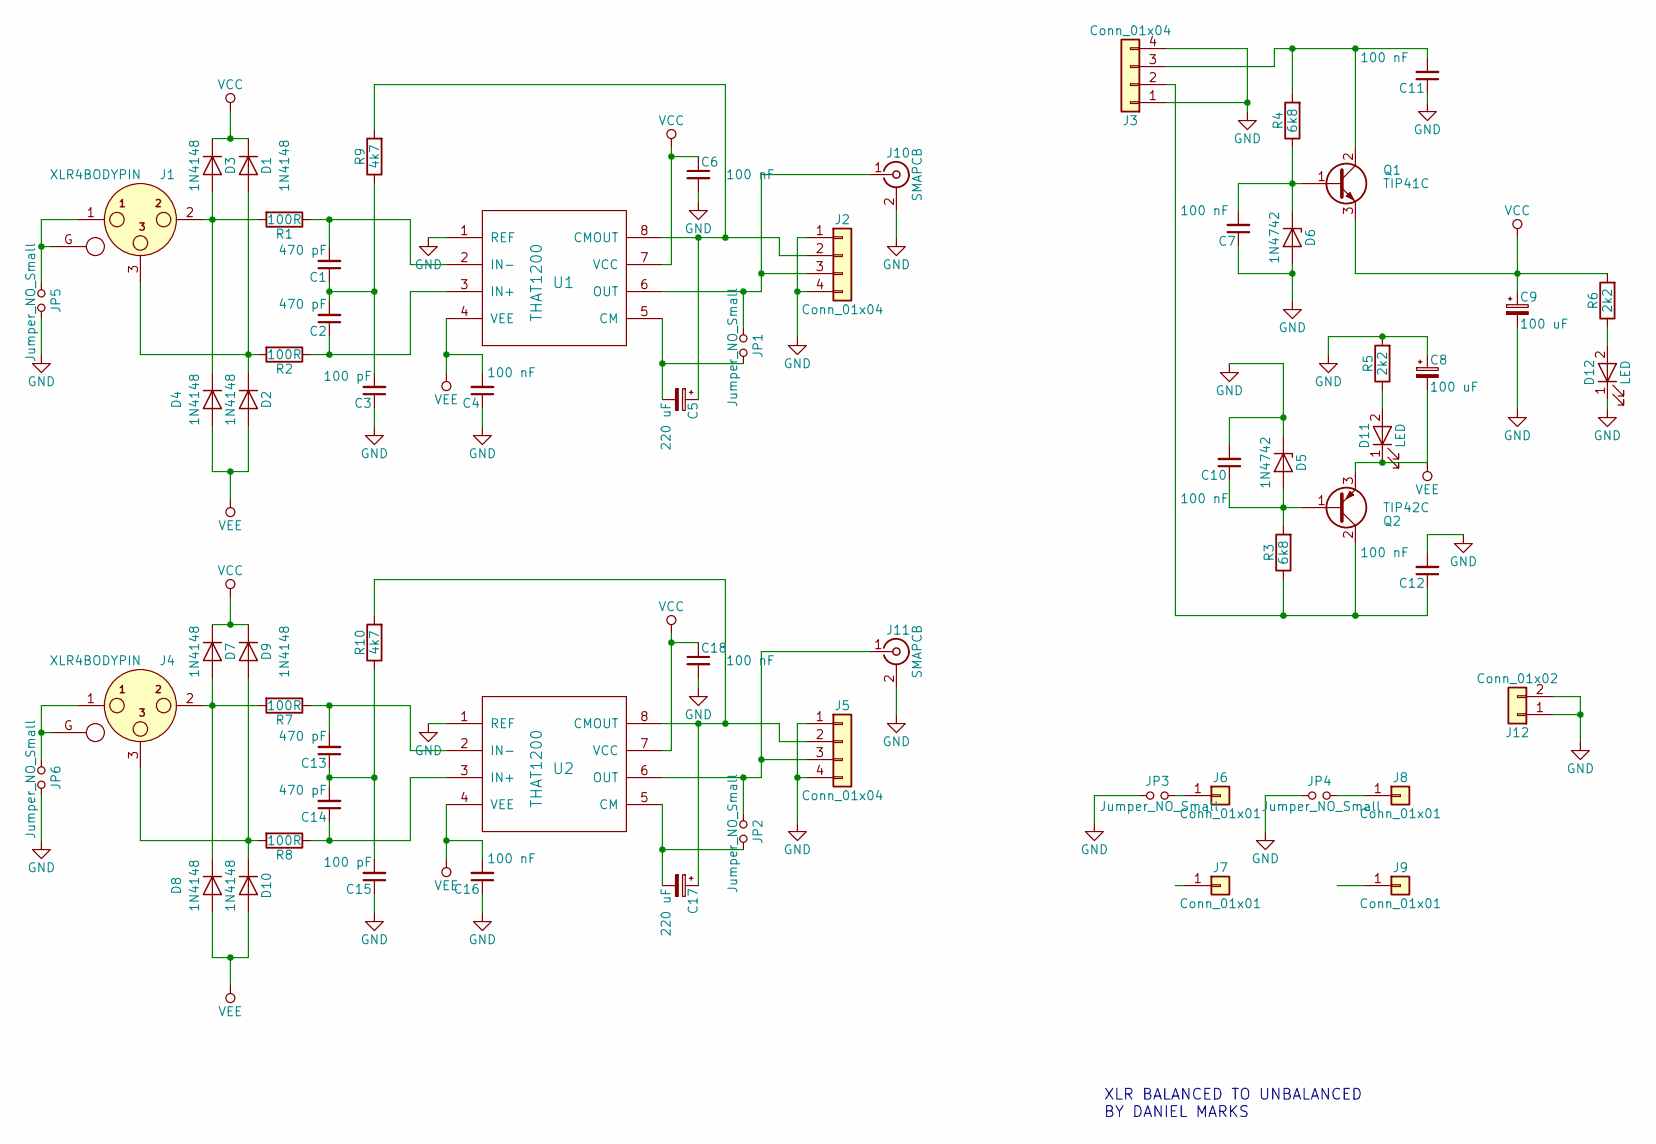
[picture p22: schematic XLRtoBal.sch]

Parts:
C1, C2, C13, C14: 470 pF; C_Disc_D5.0mm_W2.5mm_P5.00mm; LCSC C263196
C3, C15: 100 pF; C_Disc_D5.0mm_W2.5mm_P5.00mm; LCSC C400081
C4, C6, C7, C10, C11, C12, C16, C18: 100 nF; C_Disc_D5.0mm_W2.5mm_P5.00mm; LCSC C454377
C5, C17: 220 uF; CP_Radial_D8.0mm_P5.00mm; LCSC C239308
C8, C9: 100 uF; CP_Radial_D10.0mm_P5.00mm; LCSC C125770
D1, D2, D3, D4, D7, D8, D9, D10: 1N4148; D_DO-35_SOD27_P7.62mm_Horizontal; LCSC C14516
D5, D6: 1N4742; D_DO-41_SOD81_P7.62mm_Horizontal; LCSC C36751
D11, D12: LED; LED_D3.0mm
J1, J4: XLR4BODYPIN
J2, J5: Conn_01x04; TerminalBlock_bornier-4_P5.08mm; LCSC C395849
J3: Conn_01x04; TerminalBlock_bornier-4_P5.08mm_with_spade; LCSC C395849
J6, J7, J8, J9: Conn_01x01; 1pin
J10, J11: SMAPCB; SMA_THT_Jack_Straight; LCSC C496549
J12: Conn_01x02; TerminalBlock_bornier-2_P5.08mm_with_spade
JP1, JP2, JP3, JP4, JP5, JP6: Jumper_NO_Small; Pin_Header_Straight_1x02_Pitch2.54mm
Q1: TIP41C; TO-220-3_Vertical; LCSC C358526
Q2: TIP42C; TO-220-3_Vertical; LCSC C358527
R1, R2, R7, R8: 100R; R_Axial_DIN0207_L6.3mm_D2.5mm_P7.62mm_Horizontal; LCSC C57438
R3, R4: 6k8; R_Axial_DIN0309_L9.0mm_D3.2mm_P12.70mm_Horizontal; LCSC C176446
R5, R6: 2k2; R_Axial_DIN0207_L6.3mm_D2.5mm_P7.62mm_Horizontal; LCSC C58595
R9, R10: 4k7; R_Axial_DIN0207_L6.3mm_D2.5mm_P7.62mm_Horizontal; LCSC C57438
U1, U2: THAT1200; DIP-8_W7.62mm_Socket; LCSC C115171

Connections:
GND: C3.1, C4.1, C6.2, C7.1, C8.1, C9.2, C10.2, C11.1, C12.2, C15.1, C16.1, C18.2, D5.1 (K), D6.2 (A), D12.1 (K), J2.1, J2.4, J3.1, J3.4, J5.1, J5.4, J10.2 (Ext), J11.2 (Ext), J12.1, J12.2, JP3.1, JP4.1, JP5.2, JP6.2, R5.2, U1.1 (REF), U2.1 (REF)
unnamed: C1.1, C2.2, C3.2, R9.1
unnamed: C1.2, R1.1, U1.2 (IN-)
unnamed: C2.1, R2.1, U1.3 (IN+)
unnamed: C5.1, J2.2, R9.2, U1.8 (CMOUT)
unnamed: C5.2, JP1.2, U1.5 (CM)
unnamed: C7.2, D6.1 (K), Q1.1 (B), R4.1
unnamed: C10.1, D5.2 (A), Q2.1 (B), R3.2
unnamed: C11.2, J3.3, Q1.2 (C), R4.2
unnamed: C12.1, J3.2, Q2.2 (C), R3.1
unnamed: C13.1, C14.2, C15.2, R10.1
unnamed: C13.2, R7.1, U2.2 (IN-)
unnamed: C14.1, R8.1, U2.3 (IN+)
unnamed: C17.1, J5.2, R10.2, U2.8 (CMOUT)
unnamed: C17.2, JP2.2, U2.5 (CM)
unnamed: D1.2 (A), D2.1 (K), J1.3, R2.2
unnamed: D3.2 (A), D4.1 (K), J1.2, R1.2
unnamed: D7.2 (A), D8.1 (K), J4.2, R7.2
unnamed: D9.2 (A), D10.1 (K), J4.3, R8.2
unnamed: D11.2 (A), R5.1
unnamed: D12.2 (A), R6.1
unnamed: J1.1, J1.G, JP5.1
unnamed: J4.1, J4.G, JP6.1
unnamed: J6.1, JP3.2
unnamed: J8.1, JP4.2
unnamed: J2.3, J10.1 (In), JP1.1, U1.6 (OUT)
unnamed: J5.3, J11.1 (In), JP2.1, U2.6 (OUT)
VCC: C6.1, C9.1, C18.1, D1.1 (K), D3.1 (K), D7.1 (K), D9.1 (K), Q1.3 (E), R6.2, U1.7 (VCC), U2.7 (VCC)
VEE: C4.2, C8.2, C16.2, D2.2 (A), D4.2 (A), D8.2 (A), D10.2 (A), D11.1 (K), Q2.3 (E), U1.4 (VEE), U2.4 (VEE)

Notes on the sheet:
XLR BALANCED TO UNBALANCED BY DANIEL MARKS

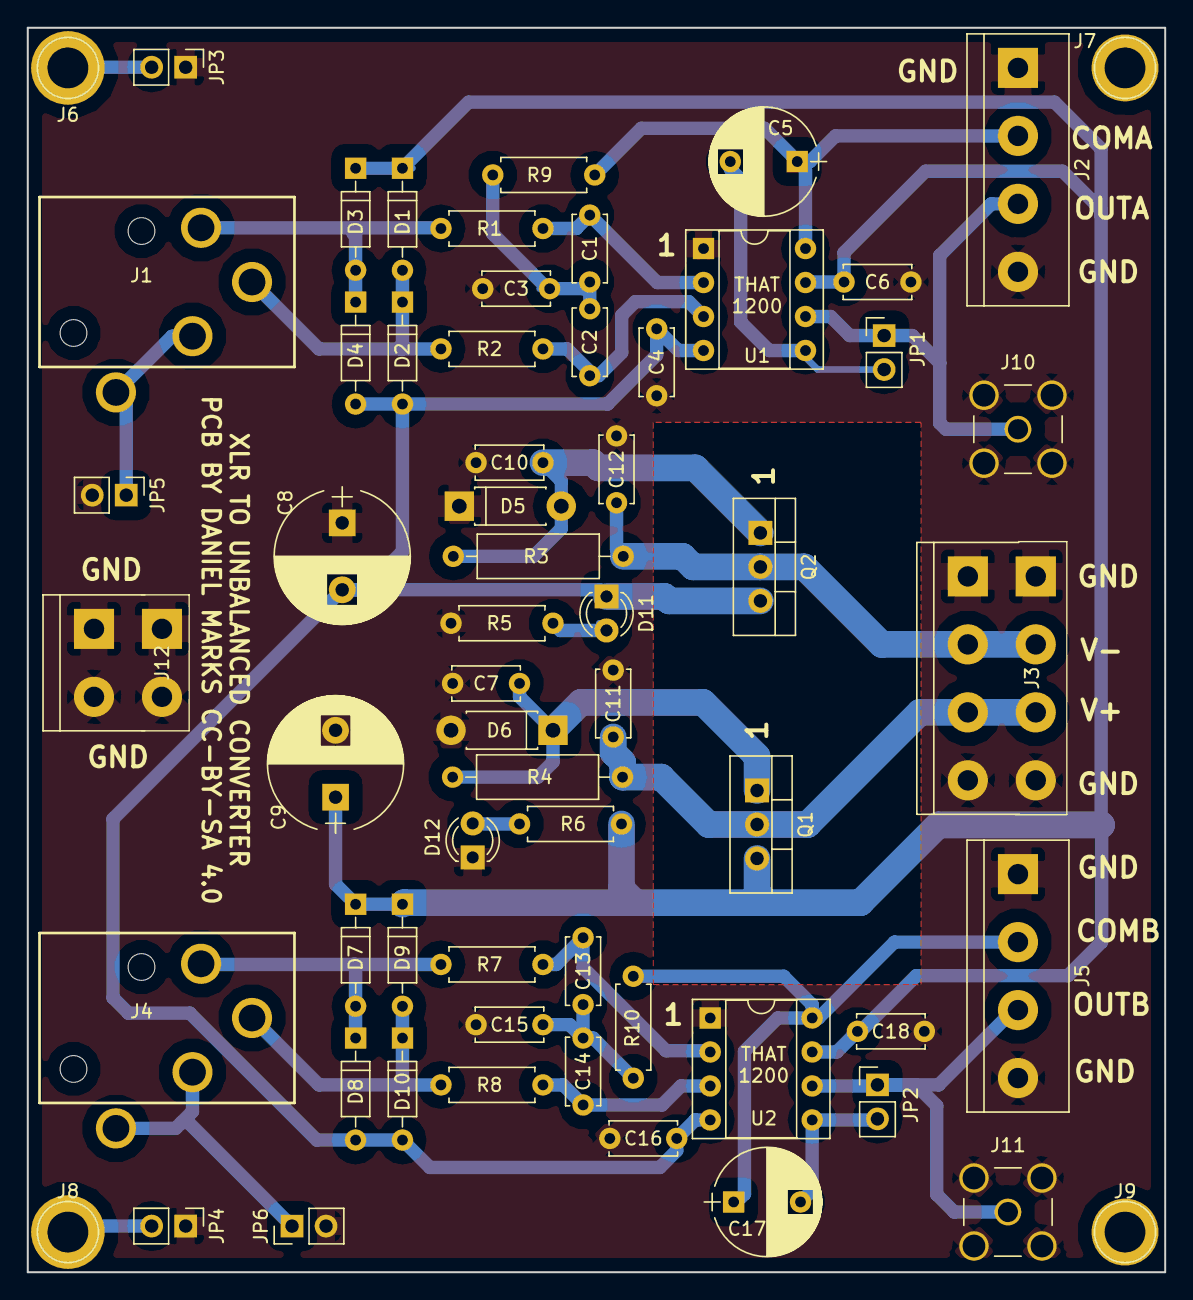
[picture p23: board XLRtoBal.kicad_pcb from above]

Board: 2 copper layers, 85.0 x 93.0 mm, 62 parts (0 on the bottom side), 29 nets.

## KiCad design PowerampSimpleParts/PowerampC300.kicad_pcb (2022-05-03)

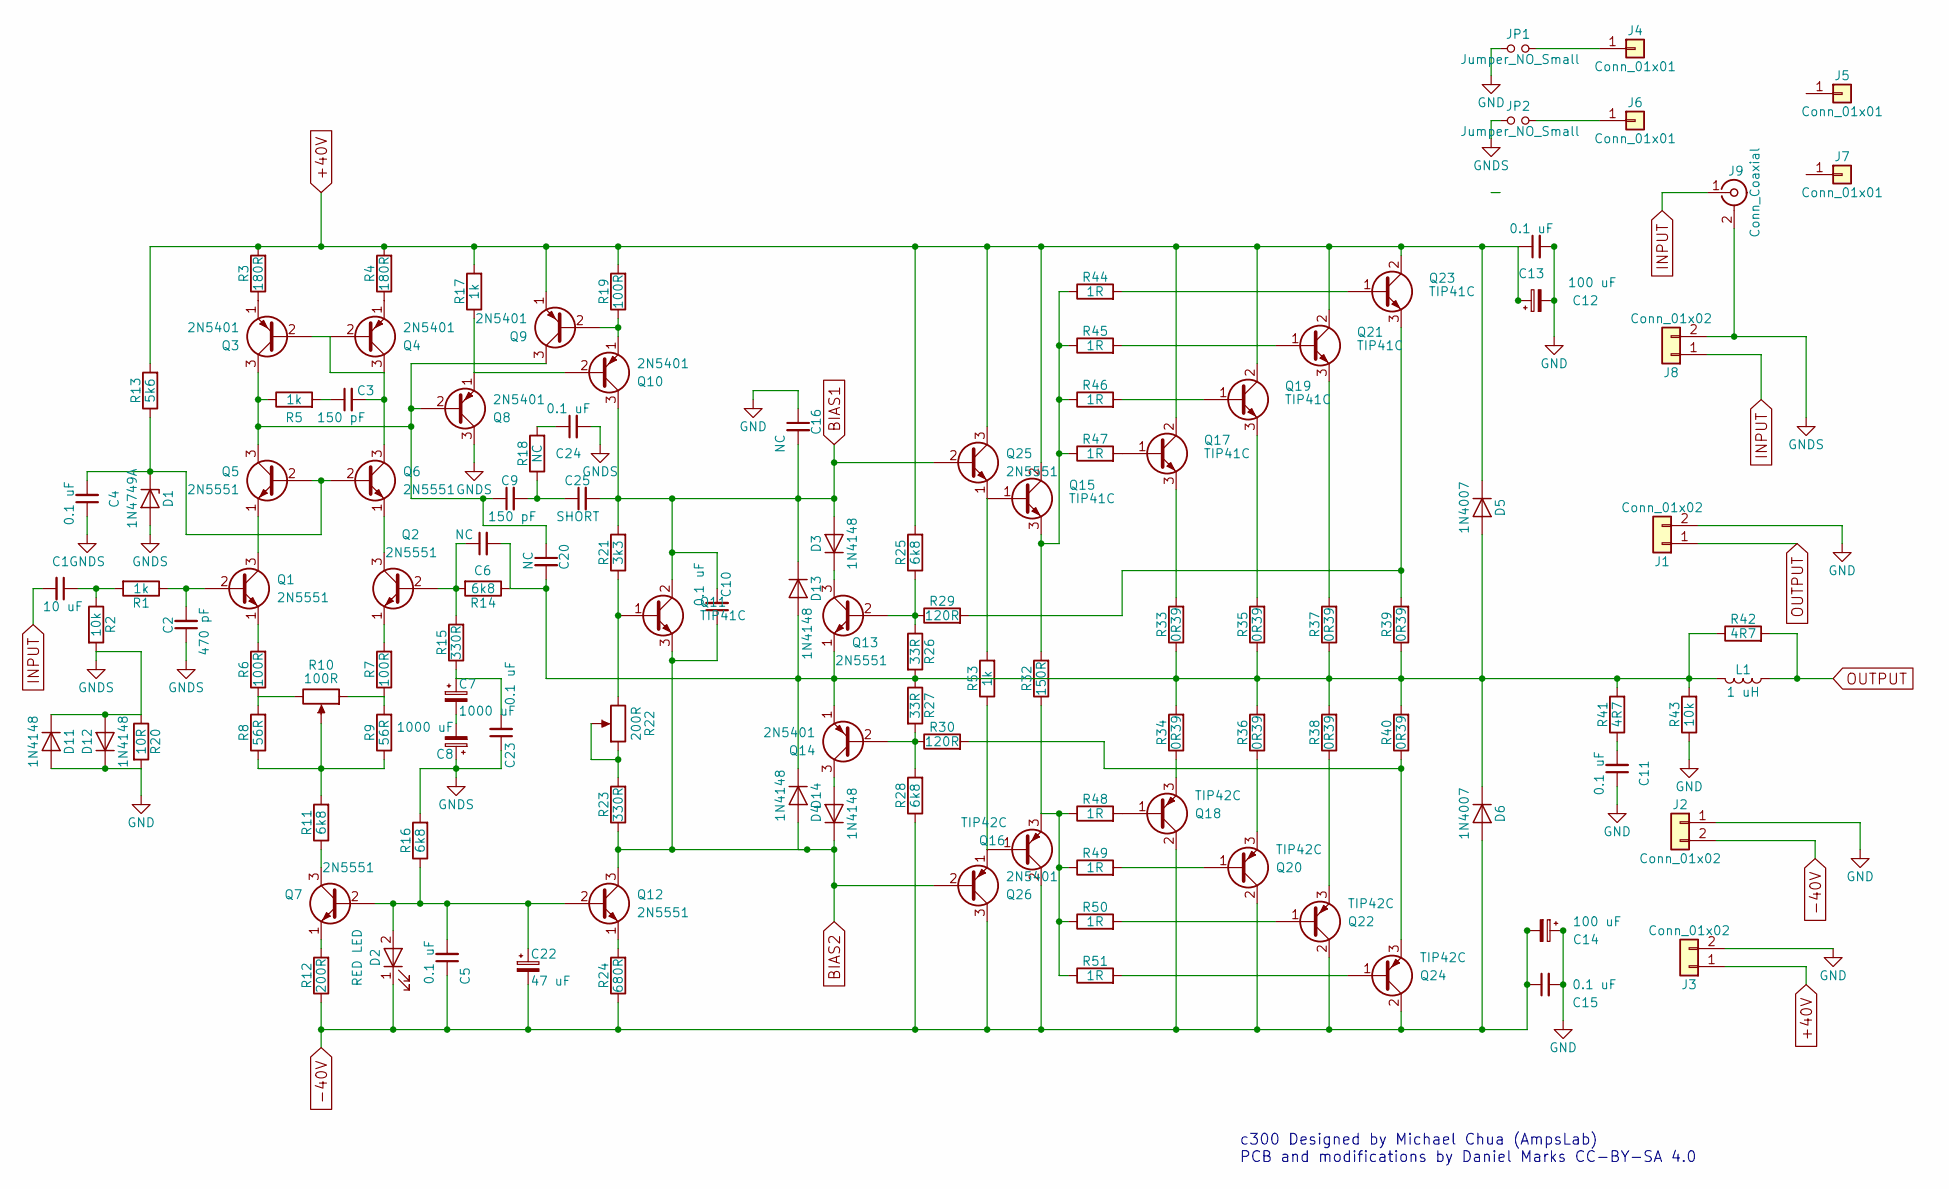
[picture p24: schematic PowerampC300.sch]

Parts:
C1: 10 uF; C_Rect_L16.5mm_W5.0mm_P15.00mm_MKT; LCSC C328801
C2: 470 pF; C_Rect_L7.0mm_W3.5mm_P5.00mm; LCSC C328872
C3: 150 pF; C_Axial_L3.8mm_D2.6mm_P7.50mm_Horizontal; LCSC C434407
C4, C5: 0.1 uF; C_Disc_D5.0mm_W2.5mm_P5.00mm; LCSC C454377
C6: NC; C_Disc_D5.0mm_W2.5mm_P5.00mm; LCSC C342428
C7, C8: 1000 uF; CP_Radial_D10.0mm_P5.00mm; LCSC C88750
C9: 150 pF; C_Disc_D5.0mm_W2.5mm_P5.00mm; LCSC C366798
C10, C11, C13, C15, C23, C24: 0.1 uF; C_Axial_L3.8mm_D2.6mm_P10.00mm_Horizontal; LCSC C390130
C12, C14: 100 uF; CP_Radial_D14.0mm_P7.50mm; LCSC C330940
C16, C20: NC; C_Disc_D5.0mm_W2.5mm_P5.00mm; LCSC C366798
C22: 47 uF; CP_Radial_D5.0mm_P2.50mm; LCSC C88750
C25: SHORT; C_Disc_D5.0mm_W2.5mm_P5.00mm; LCSC C366798
D1: 1N4749A; D_DO-41_SOD81_P7.62mm_Horizontal; LCSC C2555
D2: RED LED; LED_D3.0mm; LCSC C99771
D3, D4, D11, D12, D13, D14: 1N4148; D_DO-35_SOD27_P7.62mm_Horizontal; LCSC C125770
D5, D6: 1N4007; D_DO-41_SOD81_P7.62mm_Horizontal; LCSC C193790
J1, J2, J3: Conn_01x02; TerminalBlock_bornier-2_P5.08mm_with_spade; LCSC C395849
J4, J5, J6, J7: Conn_01x01; 1pin
J8: Conn_01x02; TerminalBlock_bornier-2_P5.08mm; LCSC C395849
J9: Conn_Coaxial; SMA_THT_Jack_Straight; LCSC C496549
JP1, JP2: Jumper_NO_Small; Pin_Header_Straight_1x02_Pitch2.54mm
L1: 1 uH; L_Radial_D16.8mm_P11.43mm_Vishay_IHB-1
Q1, Q2, Q5, Q6, Q7, Q12, Q13, Q25: 2N5551; TO-92_Inline_Wide
Q3, Q4, Q8, Q9, Q10, Q14, Q26: 2N5401; TO-92_Inline_Wide
Q11, Q15, Q17, Q19, Q21, Q23: TIP41C; TO-220-3_Vertical
Q16, Q18, Q20, Q22, Q24: TIP42C; TO-220-3_Vertical
R1, R17: 1k; R_Axial_DIN0207_L6.3mm_D2.5mm_P7.62mm_Horizontal; LCSC C57435
R2: 10k; R_Axial_DIN0207_L6.3mm_D2.5mm_P7.62mm_Horizontal; LCSC C57436
R3, R4: 180R; R_Axial_DIN0207_L6.3mm_D2.5mm_P7.62mm_Horizontal; LCSC C172976
R5: 1k; R_Axial_DIN0207_L6.3mm_D2.5mm_P7.62mm_Horizontal; LCSC C173036
R6, R7: 100R; R_Axial_DIN0207_L6.3mm_D2.5mm_P7.62mm_Horizontal; LCSC C172966
R8, R9: 56R; R_Axial_DIN0207_L6.3mm_D2.5mm_P7.62mm_Horizontal; LCSC C119298
R10: 100R; Potentiometer_Trimmer_Bourns_3296W; LCSC C83688
R11: 6k8; R_Axial_DIN0411_L9.9mm_D3.6mm_P12.70mm_Horizontal; LCSC C176446
R12: 200R; R_Axial_DIN0207_L6.3mm_D2.5mm_P7.62mm_Horizontal; LCSC C58613
R13: 5k6; R_Axial_DIN0411_L9.9mm_D3.6mm_P12.70mm_Horizontal; LCSC C138185
R14: 6k8; R_Axial_DIN0207_L6.3mm_D2.5mm_P7.62mm_Horizontal; LCSC C57436
R15: 330R; R_Axial_DIN0207_L6.3mm_D2.5mm_P7.62mm_Horizontal; LCSC C58608
R16: 6k8; R_Axial_DIN0309_L9.0mm_D3.2mm_P12.70mm_Horizontal; LCSC C176446
R18: NC; R_Axial_DIN0207_L6.3mm_D2.5mm_P7.62mm_Horizontal; LCSC C173010
R19: 100R; R_Axial_DIN0207_L6.3mm_D2.5mm_P7.62mm_Horizontal; LCSC C172976
R20: 10R; R_Axial_DIN0207_L6.3mm_D2.5mm_P7.62mm_Horizontal; LCSC C173010
R21: 3k3; R_Axial_DIN0207_L6.3mm_D2.5mm_P7.62mm_Horizontal; LCSC C173010
R22: 200R; Potentiometer_Trimmer_Bourns_3296W; LCSC C83685
R23: 330R; R_Axial_DIN0207_L6.3mm_D2.5mm_P7.62mm_Horizontal; LCSC C172973
R24: 680R; R_Axial_DIN0207_L6.3mm_D2.5mm_P7.62mm_Horizontal; LCSC C119298
R25, R28: 6k8; R_Axial_DIN0411_L9.9mm_D3.6mm_P15.24mm_Horizontal; LCSC C138189
R26, R27: 33R; R_Axial_DIN0207_L6.3mm_D2.5mm_P7.62mm_Horizontal; LCSC C173006
R29, R30: 120R; R_Axial_DIN0207_L6.3mm_D2.5mm_P7.62mm_Horizontal; LCSC C172969
R32: 150R; R_Axial_DIN0411_L9.9mm_D3.6mm_P12.70mm_Horizontal; LCSC C173006
R33, R34, R35, R36, R37, R38, R39, R40: 0R39; R_Axial_DIN0614_L14.3mm_D5.7mm_P15.24mm_Horizontal; LCSC C334290
R41: 4R7; R_Axial_DIN0309_L9.0mm_D3.2mm_P12.70mm_Horizontal; LCSC C57725
R42: 4R7; R_Axial_DIN0411_L9.9mm_D3.6mm_P15.24mm_Horizontal; LCSC C138189
R43: 10k; R_Axial_DIN0309_L9.0mm_D3.2mm_P12.70mm_Horizontal; LCSC C57725
R44, R45, R46, R47, R48, R49, R50, R51: 1R; R_Axial_DIN0411_L9.9mm_D3.6mm_P15.24mm_Horizontal; LCSC C138189
R53: 1k; R_Axial_DIN0207_L6.3mm_D2.5mm_P7.62mm_Horizontal; LCSC C172973

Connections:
+40V: C12.1, C13.1, D5.1 (K), J3.1, Q9.1 (E), Q15.2 (C), Q17.2 (C), Q19.2 (C), Q21.2 (C), Q23.2 (C), Q25.3 (C), R3.2, R4.2, R13.2, R17.2, R19.2, R25.2
-40V: C5.1, C14.2, C15.1, C22.2, D2.1 (K), D6.2 (A), J2.2, Q16.2 (C), Q18.2 (C), Q20.2 (C), Q22.2 (C), Q24.2 (C), Q26.3 (C), R12.1, R24.1, R28.1
BIAS1: C10.2, C16.2, C25.2, D3.2 (A), D13.1 (K), Q10.3 (C), Q11.2 (C), Q25.2 (B), R21.2
BIAS2: C10.1, D4.1 (K), D14.2 (A), Q11.3 (E), Q12.3 (C), Q26.2 (B), R23.1
GND: C11.1, C12.2, C13.2, C14.1, C15.2, C16.1, D11.2 (A), D12.1 (K), J1.2, J2.1, J3.2, JP1.1, R20.2, R43.1
GNDS: C2.1, C4.1, C8.1, C23.1, C24.2, D1.2 (A), D11.1 (K), D12.2 (A), J8.2, J9.2 (Ext), JP2.1, Q8.3 (C), R2.2, R16.2, R20.1
INPUT: C1.2, J8.1, J9.1 (In)
unnamed: C1.1, R1.2, R2.1
unnamed: C2.2, Q1.2 (B), R1.1
unnamed: C3.1, R5.2
unnamed: C3.2, Q3.2 (B), Q4.2 (B), Q4.3 (C), Q6.3 (C)
unnamed: C4.2, D1.1 (K), Q5.2 (B), Q6.2 (B), R13.1
unnamed: C6.1, Q2.2 (B), R14.2, R15.2
unnamed: C7.2, C8.2
unnamed: C11.2, R41.1
unnamed: C9.1, C20.1, Q3.3 (C), Q5.3 (C), Q8.2 (B), Q9.3 (C), R5.1
unnamed: C6.2, C20.2, D5.2 (A), D6.1 (K), D13.2 (A), D14.1 (K), L1.2, Q13.1 (E), Q14.1 (E), R14.1, R26.2, R27.1, R33.1, R34.2, R35.1, R36.2, R37.1, R38.2, R39.1, R40.2, R41.2, R42.1, R43.2
unnamed: C5.2, C22.1, D2.2 (A), Q7.2 (B), Q12.2 (B), R16.1
unnamed: C7.1, C23.2, R15.1
unnamed: C24.1, R18.2
unnamed: C9.2, C25.1, R18.1
unnamed: D3.1 (K), Q13.3 (C)
unnamed: D4.2 (A), Q14.3 (C)
unnamed: J4.1, JP1.2
unnamed: J6.1, JP2.2
unnamed: Q1.1 (E), R6.2
unnamed: Q1.3 (C), Q5.1 (E)
unnamed: Q2.1 (E), R7.2
unnamed: Q2.3 (C), Q6.1 (E)
unnamed: Q3.1 (E), R3.1
unnamed: Q4.1 (E), R4.1
unnamed: Q7.1 (E), R12.2
unnamed: Q7.3 (C), R11.1
unnamed: Q9.2 (B), Q10.1 (E), R19.1
unnamed: Q8.1 (E), Q10.2 (B), R17.1
unnamed: Q11.1 (B), R21.1, R22.3
unnamed: Q12.1 (E), R24.2
unnamed: Q13.2 (B), R25.1, R26.1, R29.1
unnamed: Q14.2 (B), R27.2, R28.2, R30.1
unnamed: Q15.1 (B), Q25.1 (E), R53.2
unnamed: Q15.3 (E), R32.2, R44.1, R45.1, R46.1, R47.1
unnamed: Q16.1 (B), Q26.1 (E), R53.1
unnamed: Q16.3 (E), R32.1, R48.1, R49.1, R50.1, R51.1
unnamed: Q17.1 (B), R47.2
unnamed: Q17.3 (E), R33.2
unnamed: Q18.1 (B), R48.2
unnamed: Q18.3 (E), R34.1
unnamed: Q19.1 (B), R46.2
unnamed: Q19.3 (E), R35.2
unnamed: Q20.1 (B), R49.2
unnamed: Q20.3 (E), R36.1
unnamed: Q21.1 (B), R45.2
unnamed: Q21.3 (E), R37.2
unnamed: Q22.1 (B), R50.2
unnamed: Q22.3 (E), R38.1
unnamed: Q23.1 (B), R44.2
unnamed: Q23.3 (E), R29.2, R39.2
unnamed: Q24.1 (B), R51.2
unnamed: Q24.3 (E), R30.2, R40.1
unnamed: R7.1, R9.2, R10.1
unnamed: R8.1, R9.1, R10.2, R11.2
unnamed: R6.1, R8.2, R10.3
unnamed: R22.1, R22.2, R23.2
OUTPUT: J1.1, L1.1, R42.2

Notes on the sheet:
c300 Designed by Michael Chua (AmpsLab) PCB and modifications by Daniel Marks CC-BY-SA 4.0

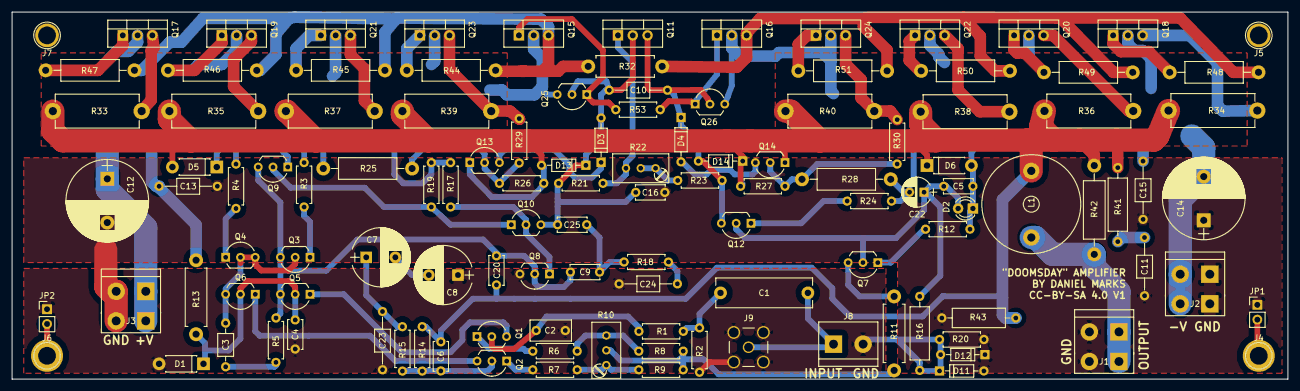
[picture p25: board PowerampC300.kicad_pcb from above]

Board: 2 copper layers, 219.0 x 63.0 mm, 120 parts (0 on the bottom side), 64 nets.

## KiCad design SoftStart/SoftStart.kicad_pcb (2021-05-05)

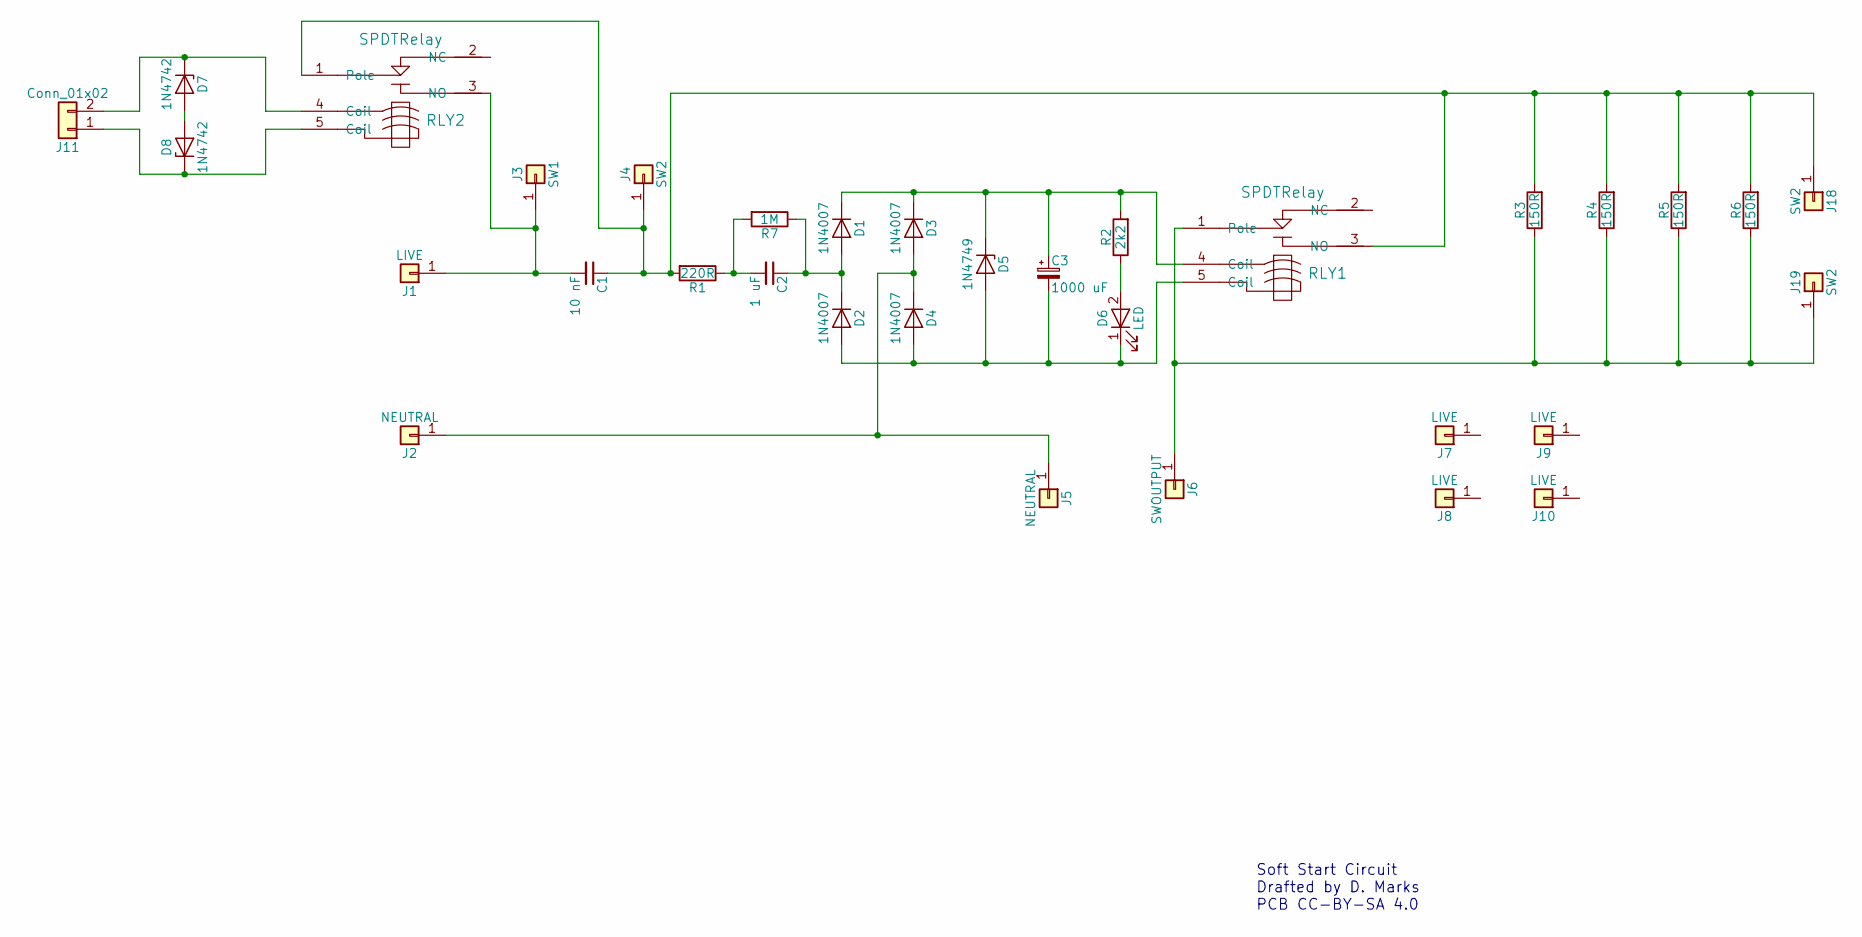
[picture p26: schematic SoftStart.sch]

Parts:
C1: 10 nF; C_Rect_L11.5mm_W4.5mm_P10.00mm_MKT; LCSC C342770
C2: 1 uF; C_Rect_L24.0mm_W10.1mm_P22.50mm_MKT; LCSC C390065
C3: 1000 uF; CP_Radial_D10.0mm_P5.00mm; LCSC C338226
D1, D2, D3, D4: 1N4007; D_DO-41_SOD81_P7.62mm_Horizontal; LCSC C193790
D5: 1N4749; D_DO-41_SOD81_P7.62mm_Horizontal; LCSC C2552
D6: LED; LED_D3.0mm; LCSC C99771
D7, D8: 1N4742; D_DO-41_SOD81_P7.62mm_Horizontal; LCSC C2552
J1: LIVE; SpadeTerminal635
J2, J5: NEUTRAL; SpadeTerminal635
J3: SW1; SpadeTerminal635
J4, J18, J19: SW2; SpadeTerminal635
J6: SWOUTPUT; SpadeTerminal635
J7, J8, J9, J10: LIVE; 1pin
J11: Conn_01x02; TerminalBlock_bornier-2_P5.08mm
R1: 220R; R_Axial_Power_L20.0mm_W6.4mm_P22.40mm; LCSC C334296
R2: 2k2; R_Axial_DIN0207_L6.3mm_D2.5mm_P7.62mm_Horizontal; LCSC C58595
R3, R4, R5, R6: 150R; R_Axial_Power_L20.0mm_W6.4mm_P22.40mm; LCSC C334292
R7: 1M; R_Axial_DIN0207_L6.3mm_D2.5mm_P7.62mm_Horizontal; LCSC C334296
RLY1, RLY2: SPDTRelay; SMIHRelay; LCSC C133339

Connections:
unnamed: C1.1, J4.1, J18.1, R1.2, R3.2, R4.2, R5.2, R6.2, RLY1.3 (NO), RLY2.1 (Pole)
unnamed: C1.2, J1.1, J3.1, RLY2.3 (NO)
unnamed: C2.1, D1.2 (A), D2.1 (K), R7.1
unnamed: C2.2, R1.1, R7.2
unnamed: C3.1, D1.1 (K), D3.1 (K), D5.1 (K), R2.2, RLY1.4 (Coil)
unnamed: C3.2, D2.2 (A), D4.2 (A), D5.2 (A), D6.1 (K), RLY1.5 (Coil)
unnamed: D3.2 (A), D4.1 (K), J2.1, J5.1
unnamed: D6.2 (A), R2.1
unnamed: D7.1 (K), J11.2, RLY2.4 (Coil)
unnamed: D7.2 (A), D8.2 (A)
unnamed: D8.1 (K), J11.1, RLY2.5 (Coil)
unnamed: J6.1, J19.1, R3.1, R4.1, R5.1, R6.1, RLY1.1 (Pole)

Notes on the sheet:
Soft Start Circuit Drafted by D. Marks PCB CC-BY-SA 4.0

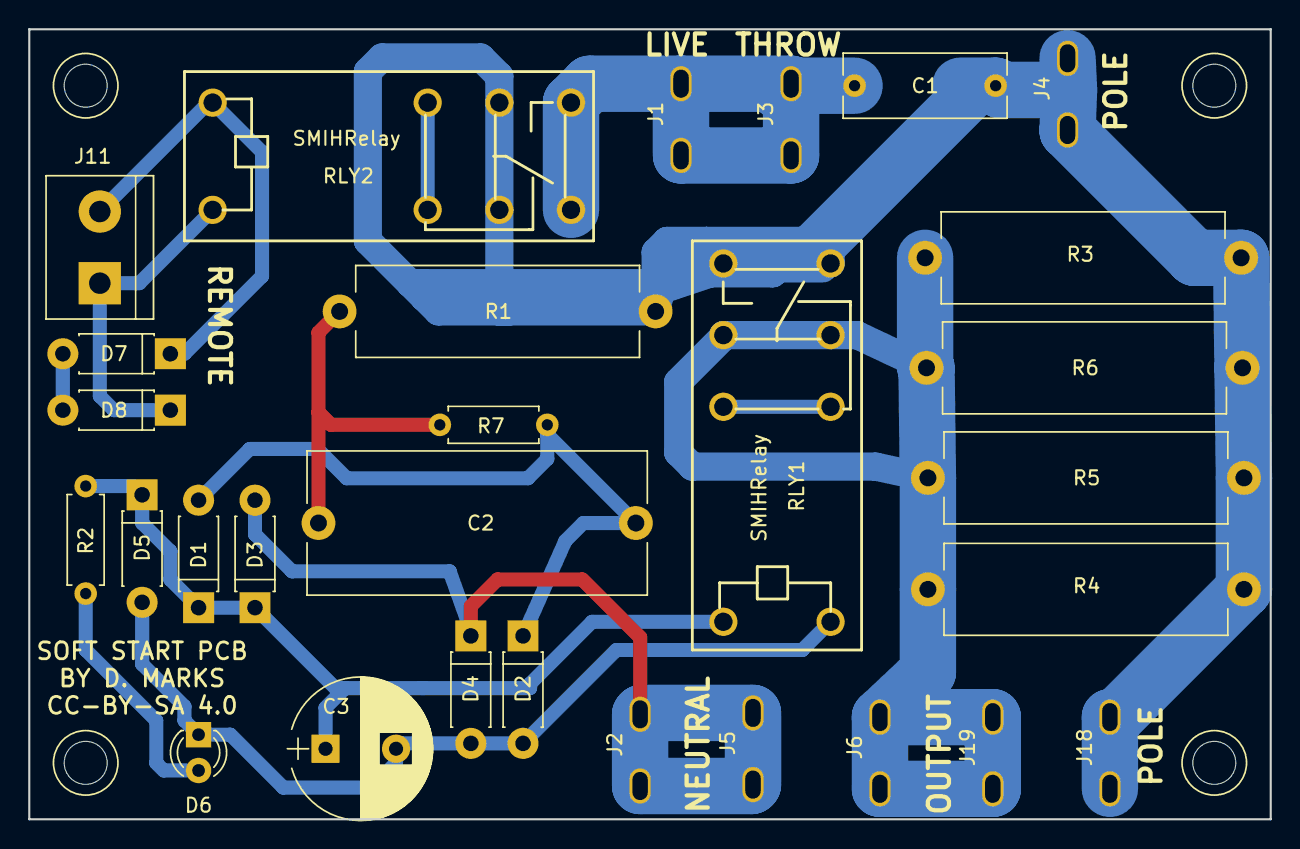
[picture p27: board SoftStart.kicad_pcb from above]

Board: 2 copper layers, 88.0 x 56.0 mm, 33 parts (0 on the bottom side), 12 nets.

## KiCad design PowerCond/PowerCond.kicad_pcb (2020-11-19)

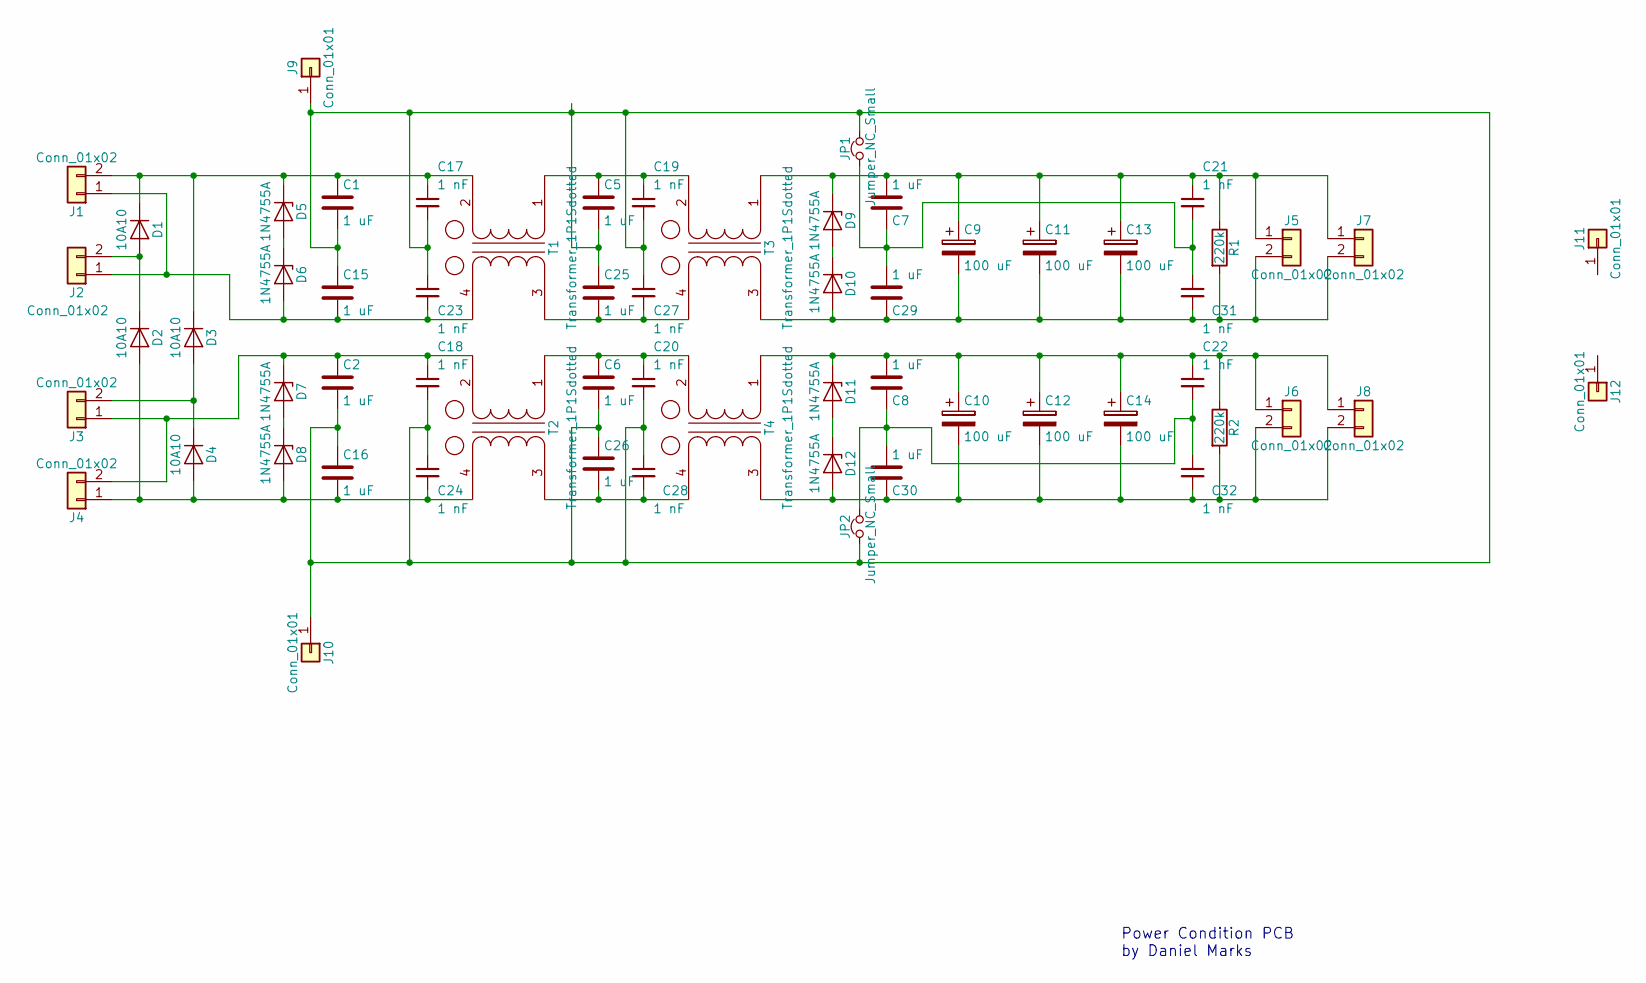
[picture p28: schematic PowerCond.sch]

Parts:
C1, C2, C5, C6, C7, C8, C15, C16, C25, C26, C29, C30: 1 uF; C_Axial_L5.1mm_D3.1mm_P12.50mm_Horizontal; LCSC C178471
C9, C10, C11, C12, C13, C14: 100 uF; CP_Radial_D14.0mm_P7.50mm; LCSC C330940
C17, C18, C20, C21, C22, C23, C24, C27, C28, C31, C32: 1 nF; C_Disc_D5.0mm_W2.5mm_P5.00mm; LCSC C249151
C19: 1 nF; C_Disc_D5.0mm_W2.5mm_P5.00mm
D1, D2, D3, D4: 10A10; D_P600_R-6_P12.70mm_Horizontal; LCSC C106904
D5, D6, D7, D8, D9, D10, D11, D12: 1N4755A; D_DO-41_SOD81_P7.62mm_Horizontal; LCSC C8043
J1, J2, J3, J4, J5, J6, J7, J8: Conn_01x02; TerminalBlock_bornier-2_P5.08mm_with_spade; LCSC C395849
J9, J10, J11, J12: Conn_01x01; 1pin
JP1, JP2: Jumper_NC_Small; Pin_Header_Straight_1x02_Pitch2.54mm
R1, R2: 220k; R_Axial_DIN0309_L9.0mm_D3.2mm_P12.70mm_Horizontal
T1, T2, T4: Transformer_1P1Sdotted; GenericCMCL3
T3: Transformer_1P1Sdotted; GenericCMCL3; LCSC C249151

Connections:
unnamed: C1.1, C17.1, D1.1 (K), D3.1 (K), D5.1 (K), J1.2, T1.2 (AB)
unnamed: C1.2, C2.2, C5.2, C6.2, C15.1, C16.1, C17.2, C18.2, C19.2, C20.2, C23.1, C24.1, C25.1, C26.1, C27.1, C28.1, J9.1, J10.1, JP1.2, JP2.1
unnamed: C8.2, C10.1, C12.1, C14.1, C22.1, D11.1 (K), J6.1, J8.1, R2.1, T4.1 (AA)
unnamed: C10.2, C12.2, C14.2, C30.1, C32.2, D12.2 (A), J6.2, J8.2, R2.2, T4.3 (SA)
unnamed: C7.2, C9.1, C11.1, C13.1, C21.1, D9.1 (K), J5.1, J7.1, R1.1, T3.1 (AA)
unnamed: C9.2, C11.2, C13.2, C29.1, C31.2, D10.2 (A), J5.2, J7.2, R1.2, T3.3 (SA)
unnamed: C15.2, C23.2, D6.2 (A), J1.1, J2.1, T1.4 (SB)
unnamed: C16.2, C24.2, D2.2 (A), D4.2 (A), D8.2 (A), J4.1, T2.4 (SB)
unnamed: C2.1, C18.1, D7.1 (K), J3.1, J4.2, T2.2 (AB)
unnamed: C5.1, C19.1, T1.1 (AA), T3.2 (AB)
unnamed: C6.1, C20.1, T2.1 (AA), T4.2 (AB)
unnamed: C7.1, C21.2, C29.2, C31.1, JP1.1
unnamed: C8.1, C22.2, C30.2, C32.1, JP2.2
unnamed: C25.2, C27.2, T1.3 (SA), T3.4 (SB)
unnamed: C26.2, C28.2, T2.3 (SA), T4.4 (SB)
unnamed: D1.2 (A), D2.1 (K), J2.2
unnamed: D3.2 (A), D4.1 (K), J3.2
unnamed: D5.2 (A), D6.1 (K)
unnamed: D7.2 (A), D8.1 (K)
unnamed: D9.2 (A), D10.1 (K)
unnamed: D11.2 (A), D12.1 (K)

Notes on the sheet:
Power Condition PCB by Daniel Marks

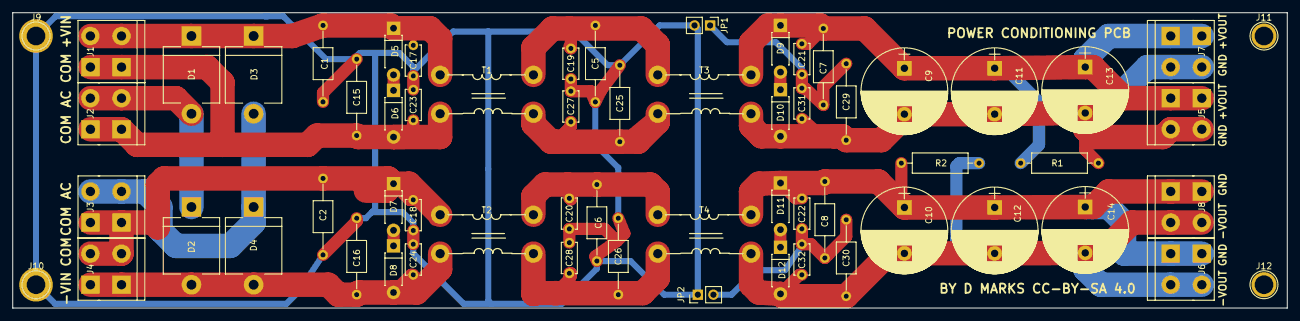
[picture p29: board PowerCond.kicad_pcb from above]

Board: 2 copper layers, 208.3 x 48.3 mm, 62 parts (0 on the bottom side), 21 nets.

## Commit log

2020-08-18 Added power condition board
    [PowerCond.kicad_pcb, PowerCond.sch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]
2020-08-19 Added XLRtoBal
    [PowerCond.kicad_pcb, PowerCond.sch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]
2020-08-20 Fixed XLR footprint
    [XLRtoBal.kicad_pcb, XLRtoBal.sch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]
2020-08-20 Changed bootstrap capacitor
    [XLRtoBal.kicad_pcb, XLRtoBal.sch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]
2020-08-21 Added credit where credit is due
    [PowerampC300-B.Cu.gbr, PowerampC300-B.Mask.gbr, PowerampC300-B.SilkS.gbr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]
2020-08-22 Added soft start circuit
    [PowerCond.kicad_pcb, PowerCond.sch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]
2020-08-25 Submitted to JLCPCB 2020-08-24
    [PowerCond.sch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]
2020-08-25 Added BOM
    [PowerCond-BOM.ods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]
2020-08-26 Fixed nasty bug in soft start
    [SoftStart-B.Cu.gbr, SoftStart-B.Mask.gbr, SoftStart-B.SilkS.gbr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]
2020-09-07 Changed softstart and Poweramp to TO-220 transistors
    [PowerCond.kicad_pcb, PowerCond.sch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]
2020-09-16 Changed to 2N5551/2N5401 from BC546C/BC556C transistors
    [PowerCond.kicad_pcb, PowerCond.sch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]
2020-09-18 Some more layout changed and XlrtoBal fix
    [PowerampC300-BOM.ods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]
2020-09-21 JLCPCB order 2020-09-21
    [PowerCond.kicad_pcb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]
2020-10-12 Working design 2020-10-12
    [PowerampC300-B.Cu.gbr, PowerampC300-B.Mask.gbr, PowerampC300-B.SilkS.gbr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]
2020-10-13 Changed grounding and star layout
    [PowerampC300-B.Cu.gbr, PowerampC300-B.Mask.gbr, PowerampC300-B.SilkS.gbr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]
2020-10-14 Sample feedback from output directly
    [PowerampC300-B.Cu.gbr, PowerampC300-B.Mask.gbr, PowerampC300-B.SilkS.gbr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]
2020-10-14 Moved Q1 and Q2 together
    [PowerampC300-BOM.ods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]
2020-10-14 Redid gerbers and files
    [PowerampC300-B.Cu.gbr, PowerampC300-B.Mask.gbr, PowerampC300-B.SilkS.gbr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]
2020-10-17 Added instructions
    [PowerCond-BOM.ods, PowerampC300-BOM.ods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]
2020-10-18 Added option for spade terminal power connections
    [PowerCond.kicad_pcb, PowerCond.sch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]
2020-10-18 Added Simulations
    [C300_SpiceModel_Faster_2N5551.sch, C300_SpiceModel_Faster_2N5551_TPC.sch, C300_SpiceModel_Faster_2N5551_TPC_openloop.sch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]
2020-10-20 Added OITPC compensation
    [C300_SpiceModel_Faster_2N5551_OITPC.sch, C300_SpiceModel_Faster_2N5551_OITPC_openloop.sch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]
2020-10-20 Added drill pattern template
2020-10-22 Redid star scheme again, added grounding diagram, modified drill template
    [C300_SpiceModel_Faster_2N5551_TPC.sch, C300_SpiceModel_Faster_2N5551_TPC_grounding.sch, PowerampC300-BOM.ods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]
2020-11-01 Changed components for lower quiescent power
    [C300_SpiceModel_Faster_2N5551.sch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]
2020-11-19 Added base stopper resistors
    [C300_SpiceModel_Faster_2N5551_Cordell.sch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]
2021-01-03 Modified soft start to have wire jumper over resistors
    [C300_SpiceModel_Faster_2N5551.sch, C300_SpiceModel_Faster_2N5551_Cordell_Square.sch, C300_SpiceModel_Faster_2N5551_Cordell_TPC.sch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]
2021-05-05 Additions of optional zener diodes to limit current surges
    [C300_SpiceModel_Faster_2N5551_Cordell.sch, C300_SpiceModel_Faster_2N5551_IRFP240.sch, C300_SpiceModel_Faster_2N5551_OITPC.sch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]
2021-05-11 Changed to use optotriac shutoff of bias
    [C300_SpiceModel_Faster_2N5551_Cordell.sch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]
2021-06-06 Added back Q9 transistor for Q8 protection
    [C300_SpiceModel_Faster_2N5551_Cordell.sch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]
2021-06-25 Added the PowerampSimpleParts version with TIP41/42
    [C300_SpiceModel_Faster_2N5551_Cordell_Triple.sch, C300_SpiceModel_Faster_2N5551_Cordell_VasCascode.sch, C300_SpiceModel_Faster_2N5551_TIP4142.sch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]
2021-06-28 Minor tweaks to PowerampSimpleParts
    [C300_SpiceModel_Faster_2N5551_Cordell.sch, C300_SpiceModel_Faster_2N5551_TIP3536.sch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]
2021-08-11 A few minor tweaks to PowerampSimpleParts layout
    [C300_SpiceModel_Faster_2N5551_Cordell.sch, C300_SpiceModel_Faster_2N5551_Cordell_Triple_VASCascode.sch, C300_SpiceModel_Faster_2N5551_Cordell_VasCascode.sch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]
2022-02-24 Fixed some silkscreening
    [C300_SpiceModel_Faster_2N5551_Cordell.sch, PowerampC300-BOM.ods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]
2022-05-03 Updated gerbers
    [PowerampC300-B.Cu.gbr, PowerampC300-B.Mask.gbr, PowerampC300-B.SilkS.gbr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]
2022-05-05 Thickened traces on XLRtoBal board
    [XLRtoBal-B.Cu.gbr, XLRtoBal-B.Mask.gbr, XLRtoBal-B.SilkS.gbr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]

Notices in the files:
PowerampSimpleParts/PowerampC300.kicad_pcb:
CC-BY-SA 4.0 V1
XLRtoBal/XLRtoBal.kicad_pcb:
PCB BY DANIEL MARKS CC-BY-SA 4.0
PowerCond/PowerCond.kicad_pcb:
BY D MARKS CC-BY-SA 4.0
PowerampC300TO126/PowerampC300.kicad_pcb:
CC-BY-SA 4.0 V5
